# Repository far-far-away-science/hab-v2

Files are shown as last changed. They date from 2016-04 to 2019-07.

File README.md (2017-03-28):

# HAB Version II

Code and hardware designs for a high altitude balloon, the second version of https://github.com/far-far-away-science/hab . This version switches to a more efficient STM32L0 processor, adds support for a backup radio using LoRA, and hopes to include additional sensors.

Different licenses may apply to subsections of this repository. See the appropriate LICENSE files in the desired subdirectories.

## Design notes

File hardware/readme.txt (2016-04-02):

all hardware designs, PCBs, schematics, drawings, specs go into this folder

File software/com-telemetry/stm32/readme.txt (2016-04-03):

this folder contains STM32 SDK and CubeMX project file used to configure hardware.

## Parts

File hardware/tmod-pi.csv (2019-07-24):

Index | Quantity | Part Number | Manufacturer Part Number | Description | Customer Reference | Available | Backorder | Unit Price | Extended Price USD
1 | 1 | SAM8857-ND | SMA-J-P-H-ST-EM1 | CONN SMA JACK STR 50OHM EDGE MNT | LORA | 1 | 0 | 4.33000 | 4.33
2 | 1 | 679-2453-ND | MJTP1250 | SWITCH TACTILE SPST-NO 0.05A 12V | S1 | 1 | 0 | 0.27000 | 0.27
3 | 1 | 311-10KARCT-ND | RC0805JR-0710KL | RES SMD 10K OHM 5% 1/8W 0805 | R6 | 1 | 0 | 0.10000 | 0.10
4 | 2 | D5V0L1B2WS-7DICT-ND | D5V0L1B2WS-7 | TVS DIODE 5V 14V SOD323 | D1 D2 | 2 | 0 | 0.30000 | 0.60
5 | 2 | 1276-2926-1-ND | CL21B105KAFNFNE | CAP CER 1UF 25V X7R 0805 | C3 C5 | 2 | 0 | 0.13000 | 0.26
6 | 10 | 311-100ARCT-ND | RC0805JR-07100RL | RES SMD 100 OHM 5% 1/8W 0805 | R1 R2 R3 R4 | 10 | 0 | 0.03600 | 0.36
7 | 2 | SAM10027-ND | SSW-108-01-F-D | CONN RCPT 16POS 0.1 GOLD PCB | J2L J2R | 2 | 0 | 1.68000 | 3.36
8 | 1 | SAM10033-ND | SSW-113-01-F-D | CONN RCPT 26POS 0.1 GOLD PCB | J1 | 1 | 0 | 2.55000 | 2.55

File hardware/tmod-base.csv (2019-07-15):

Index | Quantity | Part Number | Manufacturer Part Number | Description | Customer Reference | Available | Backorder | Unit Price | Extended Price USD
1 | 12 | 311-1141-1-ND | CC0805KRX7R8BB104 | CAP CER 0.1UF 25V X7R 0805 | C1 C5 C6 C10 C12 C13 C14 C15 C17 C22 C25 C30 | 12 | 0 | 0.11300 | 1.36
2 | 2 | 399-8062-1-ND | C0805C330K5GACTU | CAP CER 33PF 50V C0G/NP0 0805 | C2 C4 | 2 | 0 | 0.12000 | 0.24
3 | 10 | 1276-2926-1-ND | CL21B105KAFNFNE | CAP CER 1UF 25V X7R 0805 | C3 C8 C16 C20 C21 C24 C28 | 10 | 0 | 0.08000 | 0.80
4 | 1 | 1276-1765-1-ND | CL21B331KBANNNC | CAP CER 330PF 50V X7R 0805 | C18 | 1 | 0 | 0.10000 | 0.10
5 | 1 | 1276-1260-1-ND | CL21B332KBANNNC | CAP CER 3300PF 50V X7R 0805 | C26 | 1 | 0 | 0.10000 | 0.10
6 | 1 | 1276-2424-1-ND | CL21B102KBANFNC | CAP CER 1000PF 50V X7R 0805 | C31 | 1 | 0 | 0.10000 | 0.10
7 | 1 | 311-3603-1-ND | CC0805KRX7R9BB101 | CAP CER 100PF 50V X7R 0805 | C19 | 1 | 0 | 0.13000 | 0.13
8 | 1 | P15450CT-ND | EEH-ZA1V151P | CAP ALUM POLY HYB 150UF 35V SMD | C23 | 1 | 0 | 2.57000 | 2.57
9 | 1 | 732-1620-1-ND | 742792040 | FERRITE BEAD 600 OHM 0805 1LN | L1 | 1 | 0 | 0.22000 | 0.22
10 | 1 | 283-4729-1-ND | MPIA4020V2-2R2-R | FIXED IND 2.2UH 3.8A 48 MOHM SMD | L2 | 1 | 0 | 1.80000 | 1.80
11 | 3 | 1276-2397-1-ND | CL21A106KACLRNC | CAP CER 10UF 25V X5R 0805 | C27 C29 C11 | 3 | 0 | 0.57000 | 1.71
12 | 1 | 1655-1529-1-ND | SD32315TR | TVS DIODE 15V 24V SOD323 | D3 | 1 | 0 | 0.52000 | 0.52
13 | 1 | 511-1578-1-ND | SML-D12M8WT86 | LED GREEN DIFFUSED 0603 SMD | D2 | 1 | 0 | 0.34000 | 0.34
14 | 2 | 399-17612-1-ND | C0805C100K5RAC7800 | CAP CER SMD 0805 10PF 10% X7R 50 | C7 C9 | 2 | 0 | 0.30000 | 0.60
15 | 2 | 296-35483-1-ND | TPS70933DBVR | IC REG LINEAR 3.3V 150MA SOT23-5 | IC1 IC10 | 2 | 0 | 1.17000 | 2.34
16 | 1 | 296-23770-1-ND | INA219AIDCNR | IC CURRENT MONITOR 1% SOT23-8 | IC2 | 1 | 0 | 2.14000 | 2.14
17 | 1 | 497-14903-ND | STM32L052C8T6 | IC MCU 32BIT 64KB FLASH 48LQFP | IC3 | 1 | 0 | 4.04000 | 4.04
18 | 1 | LMP7702MM/NOPBCT-ND | LMP7702MM/NOPB | IC OPAMP GP 2.5MHZ RRO 8VSSOP | IC5 | 1 | 0 | 3.55000 | 3.55
19 | 1 | 296-39448-1-ND | TPS62143RGTR | IC REG BUCK 5V 2A SYNC 16QFN | IC6 | 1 | 0 | 2.08000 | 2.08
20 | 1 | 296-46278-1-ND | TPS22918DBVR | IC SINGLE CHANNEL LOAD SWITCH | IC8 | 1 | 0 | 0.55000 | 0.55
21 | 1 | 828-1063-1-ND | BME280 | SENSOR PRESSURE HUMIDITY TEMP | IC9 | 1 | 0 | 8.10000 | 8.10
22 | 1 | 887-1448-1-ND | 7A-8.000MAAJ-T | CRYSTAL 8.0000MHZ 18PF SMD | Y1 | 1 | 0 | 0.72000 | 0.72
23 | 1 | 535-10241-1-ND | ABS25-32.768KHZ-6-1-T | CRYSTAL 32.7680KHZ 6PF SMD | Y2 | 1 | 0 | 0.68000 | 0.68
24 | 1 | 1516-1131-1-ND | QBLP679E-RGB | LED RGB DIFFUSED 6PLCC SMD | LED1 | 1 | 0 | 0.92000 | 0.92
25 | 1 | A121350-ND | 1546215-2 | TERM BLK 2P SIDE ENT 2.54MM PCB | J4 | 1 | 0 | 1.48000 | 1.48
26 | 2 | SAM10451-ND | ESQ-108-14-G-D | CONN SOCKET 16POS 0.1 GOLD PCB | J7 | 2 | 0 | 3.87000 | 7.74
27 | 1 | 455-1720-ND | S3B-PH-K-S(LF)(SN) | CONN HEADER R/A 3POS 2MM | J2 | 1 | 0 | 0.18000 | 0.18
28 | 1 | 455-1721-ND | S4B-PH-K-S(LF)(SN) | CONN HEADER R/A 4POS 2MM | J3 | 1 | 0 | 0.22000 | 0.22
29 | 2 | 679-2453-ND | MJTP1250 | SWITCH TACTILE SPST-NO 0.05A 12V | S1 S2 | 2 | 0 | 0.27000 | 0.54
30 | 1 | 3M5607CT-ND | 2908-05WB-MG | CONN MICRO SD CARD PUSH-PUSH R/A | J6 | 1 | 0 | 3.83000 | 3.83
31 | 2 | 311-4.70KCRCT-ND | RC0805FR-074K7L | RES SMD 4.7K OHM 1% 1/8W 0805 | R6 R16 | 2 | 0 | 0.10000 | 0.20
32 | 10 | 311-10KARCT-ND | RC0805JR-0710KL | RES SMD 10K OHM 5% 1/8W 0805 | R1 R3 R4 R5 R7 R20 R24 R25 | 10 | 0 | 0.03700 | 0.37
33 | 2 | 311-470CRCT-ND | RC0805FR-07470RL | RES SMD 470 OHM 1% 1/8W 0805 | R8 R9 | 2 | 0 | 0.10000 | 0.20
34 | 1 | 311-560CRCT-ND | RC0805FR-07560RL | RES SMD 560 OHM 1% 1/8W 0805 | R10 | 1 | 0 | 0.10000 | 0.10
35 | 3 | 311-3.30KCRCT-ND | RC0805FR-073K3L | RES SMD 3.3K OHM 1% 1/8W 0805 | R11 R17 R19 | 3 | 0 | 0.10000 | 0.30
36 | 1 | 311-330KCRCT-ND | RC0805FR-07330KL | RES SMD 330K OHM 1% 1/8W 0805 | R12 | 1 | 0 | 0.10000 | 0.10
37 | 1 | 311-820KCRCT-ND | RC0805FR-07820KL | RES SMD 820K OHM 1% 1/8W 0805 | R13 | 1 | 0 | 0.10000 | 0.10
38 | 1 | 311-220KCRCT-ND | RC0805FR-07220KL | RES SMD 220K OHM 1% 1/8W 0805 | R14 | 1 | 0 | 0.10000 | 0.10
39 | 1 | 311-430KCRCT-ND | RC0805FR-07430KL | RES SMD 430K OHM 1% 1/8W 0805 | R15 | 1 | 0 | 0.10000 | 0.10
40 | 1 | 311-680KCRCT-ND | RC0805FR-07680KL | RES SMD 680K OHM 1% 1/8W 0805 | R18 | 1 | 0 | 0.10000 | 0.10
41 | 1 | 311-100KCRCT-ND | RC0805FR-07100KL | RES SMD 100K OHM 1% 1/8W 0805 | R21 | 1 | 0 | 0.10000 | 0.10
42 | 12 | D5V0L1B2WS-7DICT-ND | D5V0L1B2WS-7 | TVS DIODE 5V 14V SOD323 | D1 D4-D14 | 12 | 0 | 0.27400 | 3.29
43 | 1 | SAM8857-ND | SMA-J-P-H-ST-EM1 | CONN SMA JACK STR 50OHM EDGE MNT | RF | 1 | 0 | 4.33000 | 4.33
44 | 1 | 311-0.01NACT-ND | RL1210FR-070R01L | RES 0.01 OHM 1% 1/2W 1210 | R22 | 1 | 0 | 0.73000 | 0.73000
45 | 1 | ADXL345BCCZ-RLCT-ND | ADXL345BCCZ-RL | ACCEL 2-16G I2C/SPI 14LGA | U2 | 1 | 0 | 8.14000 | 8.14000

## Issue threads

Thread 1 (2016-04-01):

List APRS messages formats we should be using

usaguerrilla, 2016-04-01:
- potentially with 2 GPS (which ID do we change -11?)
- we need to send this (no need to send all in one message apart from time/GPS coordinate/altitude/number of satellites:
  - time
  - GPS coordinates
  - Altitude
  - Heading
  - Speed
  - Battery voltage
  - Number of satellites
  - Message #
  - CPU temperature (need to research this)
  - Batteries temperature
  - Max acceleration experienced X,Y,Z

Might think about more stuff.

N6UDP, 2016-04-26:
Ok, so the best option is to do a separate telemetry packet after the position one.. example:
2016-04-25 20:39:31 UTC: VK5RAC-1>APNU19,EYRE2-2,qAR,VK5ZEA-1:!3423.56SS13557.24E#PHG5630/ Eyre Pen. Ui-Digi PF75XO @330m
2016-04-25 21:02:05 UTC: VK5RAC-1>TLM,EYRE2-2,qAR,VK5ZEA-1:T#091,048,138,057,021,001,00000000,SA3VFD
As for a Balloon you want it to be something like 4747.50N/12215.10WOTesting
the O being balloon.
As for the format of the telemetry http://www.eoss.org/hardware/w5vsi_gps/telemetry_gps has a good breakdown.  http://www.aprs.net/vm/DOS/TELEMTRY.HTM is the official thing.

usaguerrilla, 2016-07-02:
done

Closed 2016-07-02.

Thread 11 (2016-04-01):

Add temperature sensors and collect information from them

usaguerrilla, 2016-04-01:
- MCU temperature sensors
- Outside temperature
- Battery temperature

usaguerrilla, 2016-04-01:
save to SD and transmit over telemetry channel

usaguerrilla, 2016-04-01:
STM32L0 has sensor and calibration data for it.
http://www.st.com/web/en/resource/technical/document/datasheet/DM00141036.pdf

usaguerrilla, 2016-04-02:
We can also add external temperature sensors on different sides of the package to check how much sun is affecting temperature.

usaguerrilla, 2016-04-04:
ADC which works on SPI
http://www.ti.com/product/ads1247

usaguerrilla, 2016-04-06:
thermal adhesive for contact senosrs

http://www.amazon.com/s/ref=nb_sb_noss_2?url=search-alias%3Daps&field-keywords=Thermal+adhesive

usaguerrilla, 2016-07-08:
will create separate tasks by sensor type.

Closed 2016-07-08.

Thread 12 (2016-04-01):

Add accelerometer sensor (3D) and collect information for it

usaguerrilla, 2016-04-01:
save to SD
send max acceleration to date over telemetry radio channel

usaguerrilla, 2016-07-07:
assigned DMA to I2C.

https://github.com/far-far-away-science/hab-v2/wiki/dma_usage

usaguerrilla, 2016-07-08:
See sensors list:
https://github.com/far-far-away-science/hab-v2/wiki/sensors_list

stcarlso, 2017-09-15:
Implemented in Phoenix, accelerometer data is read and logged over serial port

Closed 2017-09-15.

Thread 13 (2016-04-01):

Add medium altitude pressure sensors and collect infromation from them

usaguerrilla, 2016-04-01:
Do we want to collect pressure close to the ground?
Do we want pressure from up high?
Pick sensors.
Need to save to SD.
Should we send it over the radio once in a while?

usaguerrilla, 2016-04-04:
http://www.ebay.com/itm/Sensore-pressione-MD-PS002-vacuum-sensor-absolute-pressure-senso-for-Arduino-/191674522193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

http://www.ebay.com/itm/Freescale-MPXV6115VC6U-vacuum-sensor-115-to-0-kPa-16-7-to-0-psi-USA-seller-/231887983618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

usaguerrilla, 2016-04-07:
for this task use one of these sensors (lower altitude ones):

http://www.digikey.com/product-search/en/sensors-transducers/pressure-sensors-transducers/1966259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

usaguerrilla, 2016-07-08:
sensor make and model are in the sensors list in wiki
this is an SPI sensor.

usaguerrilla, 2016-07-08:
Sensors list:
https://github.com/far-far-away-science/hab-v2/wiki/sensors_list

stcarlso, 2017-09-15:
BME280 sensor is implemented in Phoenix

Closed 2017-09-15.

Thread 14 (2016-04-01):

Add camera which will record balloon pop event

usaguerrilla, 2016-04-01:
Need to record pop event. No need to record full flight. Don't need very high resolution. Should be software controlled to cut power consumption.

Do we need extra MCU for it?
Save to separate SD card?

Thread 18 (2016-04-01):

Gyro-stabilized camera 1x

usaguerrilla, 2016-04-01:
Check if it's possible and how much will it weigh.

usaguerrilla, 2016-07-08:
not going to make it for V2

Closed 2016-07-08.

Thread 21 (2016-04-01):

Add LORA or other radio options to supplement APRS for package recovery

usaguerrilla, 2016-04-01:
Check power requirements.
Turn them on, once package lands.

usaguerrilla, 2016-06-07:
LORA should:

- after we turn on electronics on the ground LORA should power up and start transmitting for 5 minutes (every 15 seconds or so, duration and delay can be discussed). We want to make sure it works.
- after this it should power down
- when altitude is < 3 km LORA should again power up (as range is something like 10km) we might receive messages from it in case something is wrong with APRS and vice versa and transmit every 30 seconds or so
- when on the ground for 1st 3 hours it should keep transmitting every 15-30 seconds or so (check how much power will it consume)
- after 3 hours it should transmit every 15-30 minutes

to discuss: do we need to handle case where it landed one a moving object (river, truck) and do we need to transmit more often in this case?

stcarlso, 2017-09-15:
Implemented in Phoenix, LoRA is active at all times and transmits with APRS.

Closed 2017-09-15.

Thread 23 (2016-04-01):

Ultrasonic temperature / pressure sensor

usaguerrilla, 2016-04-01:

usaguerrilla, 2016-04-07:
Please note that priority of interrupts for this sensor will be after:
- APRS signal generation
- GPS data reception
Not sure how critical it will be to have 3rd priority.

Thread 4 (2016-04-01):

Add support to write to persistent storage SD?

usaguerrilla, 2016-04-01:
We want as much space as possible. As we want to collect data often and a lot of it. This will include all sensors data.

- choose parts (SD, FLASH, EEPROM?), > 10M? Needs discussion.
- PCB design

usaguerrilla, 2016-04-01:
For some date we need around 2-3 hours storage. For small subset we might need 12-24 hours storage.

usaguerrilla, 2016-04-01:
Also some data will have higher sampling rate than other.
- GPS -> once a second or so
- Accelerometers -> 10-100 times a second
- Temperature -> once in 1-15 seconds
We can use binary storage if we are tight on space.

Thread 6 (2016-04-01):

Add light sensors for GoPros or other ways of detecting if they are recording.

usaguerrilla, 2016-04-01:
When GoPro records light is blinking. We can add sensor of red light next to it to detect if recording is running and transmit it with telemetry.

Alternatively investigate if it's possible to get telemetry using USB or other means with GoPro4.

usaguerrilla, 2016-07-08:
See sensors list:
https://github.com/far-far-away-science/hab-v2/issues/6

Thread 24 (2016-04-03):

Migrate Copernicus GPS code to STM32

usaguerrilla, 2016-04-03:

usaguerrilla, 2016-04-06:
requirements:
* code should support recovery from temporary loss of power or reset and loading last known position to transmit over APRS (with flag of stale information).
* new position should be transmitted as soon as GPS acquires lock
* this is the 2nd highest priority after APRS signal modulation
* GPS should not be updated more than once a second

recovery data requirements:
* recovery data will be stored in EEPROM in both banks
* each bank will have ring buffer for 50 records (after we reach end we start overwriting old records). 50 was picked to prolong EEPROM lifetime.
* on reboot we will scan all records (from banks which are online, if bank is offline for writing wait for read operation to be completed before restoring the data) and use latest one
* banks will be written in round robin style (bank 1, bank 2, bank 1, etc.)

recovery record spec:
* TODO

open items:
* what will happen if during EEPROM write operation MCU reboots or has fault ISR or power off event
* how to determine buffer writing round robin order

usaguerrilla, 2016-04-06:
Unlock with wait until write is completed:
/* (1) Wait till no operation is on going */
/* (2) Check if the PELOCK is unlocked */
/* (3) Perform unlock sequence */
while ((FLASH->SR & FLASH_SR_BSY) != 0) /* (1) */
{
/* For robust implementation, add here time-out management */
}
if ((FLASH->PECR & FLASH_PECR_PELOCK) != 0) /* (2) */
{
FLASH->PEKEYR = FLASH_PEKEY1; /* (3) */
FLASH->PEKEYR = FLASH_PEKEY2;
}

usaguerrilla, 2016-04-06:
Lock with wait until write is completed:

```
/* (1) Wait till no operation is on going */
/* (2) Locks the NVM by setting PELOCK in PECR */
while ((FLASH->SR & FLASH_SR_BSY) != 0) /* (1) */
{
/* For robust implementation, add here time-out management */
}
FLASH->PECR |= FLASH_PECR_PELOCK; /* (2) */
```

usaguerrilla, 2016-04-06:
Write to data EEPROM code example
```
*(uint8_t *)(DATA_E2_ADDR+i) = DATA_BYTE;
*(uint16_t *)(DATA_E2_ADDR+j) = DATA_16B_WORD;
*(uint32_t *)(DATA_E2_ADDR) = DATA_32B_WORD;
```
DATA_E2_ADDR is an aligned address in the data EEPROM area.
i can be any integer.
j must be an even integer.

usaguerrilla, 2016-04-06:
Erase to data EEPROM code example
/* (1) Set the ERASE and DATA bits in the FLASH_PECR register
to enable page erasing */
/* (2) Write a 32-bit word value at the desired address
to start the erase sequence */
/* (3) Enter in wait for interrupt. The EOP check is done in the Flash ISR
*/
/* (6) Reset the ERASE and DATA bits in the FLASH_PECR register
to disable the page erase */
FLASH->PECR |= FLASH_PECR_ERASE | FLASH_PECR_DATA; /* (1) */
*(__IO uint32_t *)addr = (uint32_t)0; /* (2) */
__WFI(); /* (3) */
FLASH->PECR &= ~(FLASH_PECR_ERASE | FLASH_PECR_DATA); /* (4) */

Scorillo47, 2016-04-06:
My suggestion would be something along these lines (pseudo-code only - I didn’t add CRC, sequence#, Flash synchronization, etc). Sorry for the Outlook-enforced capitalization:

Bool Write(data)
{
                For(int = 0; I < maxAddressesToBeTried; i++)
                {
                                addr = PickUpNextLocation(); // alternate banks round-robin, etc.
                                For(int = 0; I < maxRetries; i++)
                                {
                                                If (Write(data, addr) == success)
                                                {
                                                                // wait a bit …

                                                                // Read after write to ensure the correct data is there
                                                                Data1 = Read(addr);
                                                                If (Data == Data1)
                                                                {
                                                                                Return true;
                                                                }
                                                }

                                                // Writing failed (bad block?)

                                                // wait a bit more …                                

                                                // retry writing on the same location maxRetries
                                }
                                // give up on this address. Try writing on the next location (up to maxAddressesToBeTried tries)
                }

                Return false;
}

usaguerrilla, 2016-04-07:
algorithm in a nutshell:

```
isDataValid(address)
{
    return true if crc(from sequence id and payload at this address) == crc(crc at this address) else false
}

recoverDataFromBank(bankAddress, currentMaxSequenceId)
{
    if (!waitUntilBankIsAvailable(TIMEOUT))
    {
        return (none, none)
    }
    data = none
    maxSequenceId = currentMaxSequenceId
    foreach (address in bankAddress)
    {
        if (isDataValid(address) && getId(address) > maxSequenceId)
        {
            data = getData(address)
            maxSequenceId = getId(address)
        }
    }
    return (data, maxSequenceId)
}

recoverGpsData(data)
{
    sequence_id maxGoodId;
    (data, sequence_id) = recoverDataFromBank(Bank1Address, none)
    (data, sequence_id) = recoverDataFromBank(Bank2Address, sequence_id)
    return data != none
}
```

usaguerrilla, 2016-04-07:
update recovery algorithm in a nutshell:

```
updateRecoveryData(data)
{
}
```

usaguerrilla, 2016-04-07:
This algorithm protects against the following problems:

* MCU resets (or experiences short power interruption) and we cannot communicate with GPS after power on
* GPS unit looses last known good position or overwrites it with the empty position message

* This algorithm / hardware design is:
* (2*N-2)x fail operational / fail safe for EEPROM individual memory cells failures (couldn't read or couldn't write at specific addresses).
* fail safe for EEPROM data banks (as we have 2 and failure of one bank will still leave system running).
* fail safe for GPS loosing last known good position

N - size of a ring buffer in one EEPROM memory bank

usaguerrilla, 2016-05-05:
code migrated. gps backup will be done by #37

Closed 2016-05-05.

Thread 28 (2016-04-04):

Infrared camera inside the case to check cooling video

usaguerrilla, 2016-04-04:

usaguerrilla, 2016-04-04:
https://www.sparkfun.com/products/11610

usaguerrilla, 2016-04-04:
Above camera might not be what we need for this. Need to test.

usaguerrilla, 2016-04-06:
https://hackaday.io/project/3000-flir-lepton-thermal-camera-breakout

http://www.digikey.com/product-detail/en/flir/500-0659-01/500-0659-01-ND/5215153

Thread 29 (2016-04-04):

Add gamma/beta/xray detector

usaguerrilla, 2016-04-04:
Make sure to estimate weight / power consumption / size before starting work.

usaguerrilla, 2016-04-10:
By Adi's estimate weight is 290gr. Way to heavy if we want to make a video!

usaguerrilla, 2016-07-08:
didn't make it for V2 as board layout is fixed now.

Closed 2016-07-08.

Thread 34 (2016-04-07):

Add high altitude pressure sensors and collect infromation from them

usaguerrilla, 2016-04-07:

usaguerrilla, 2016-04-10:
hard to get sensors to do this job. not sure if they are light. we have sensors which will work up to 25-28 km or so.

usaguerrilla, 2016-07-08:
not a target for V2

Closed 2016-07-08.

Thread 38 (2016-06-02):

Migrate UART to use DMA and UART IDLE interrupt

usaguerrilla, 2016-06-02:
AFSK modulator on release build loads CPU for 86%. I don't want UART to interrupt AFSK message generation nor I want GPS coordinates to be lost from UART.

Proposed solution:
- migrate UART to receive using DMA feature (allocate memory for more than 1 message)
- end of message can be detected by UART IDLE interrupt or DMA full and memory can be copied to ring buffer
- in main() thread parse and process NMEA messages

this will remove code from interrupts and CPU will be free to handle AFSK modulation.

Scorillo47, 2016-06-02:
86% CPU for a modulator? We should just use a faster CPU

Sent from my Windows Phone
________________________________
De la: Pavel Krupets<mailto:notifications@github.com>
Trimis: ‎02.‎06.‎2016 9:47
Către: far-far-away-science/hab-v2<mailto:hab-v2@noreply.github.com>
Subiect: [far-far-away-science/hab-v2] Migrate UART to use DMA and UART IDLE interrupt (#38)

AFSK modulator on release build loads CPU for 86%. I don't want UART to interrupt AFSK message generation nor I want GPS coordinates to be lost from UART.

Proposed solution:
- migrate UART to receive using DMA feature (allocate memory for more than 1 message)
- end of message can be detected by UART IDLE interrupt and memory can be copied to ring buffer
- in main() thread parse and process NMEA messages

this will remove code from interrupts and CPU will be free to handle AFSK modulation.

---
You are receiving this because you are subscribed to this thread.
Reply to this email directly or view it on GitHub:
https://github.com/far-far-away-science/hab-v2/issues/38

usaguerrilla, 2016-06-02:
I want this to work on a slowest CPU possible so code can be ported to circumnavigating balloon.

I did this test:
do (a * b + c / d) and write to RAM on 16MHz at 96kHz and it loaded CPU 30%. Adding read from program memory increased it to 50% so I don't think I can optimize much. Division might be slowest operation.

usaguerrilla, 2016-06-02:
By 86% I mean CPU was running at full speed and consumed 86% of available time to fill DMA buffer.

usaguerrilla, 2016-06-02:
Also DMA for UART will save us from getting to many interrupts which is good as well. I wasn't sure how to detect when UART finished transmitting but DMA buffer isn't full.

After reading specs it seems UART IDLE interrupt will be fired in this case and I can copy memory from DMA buffer to ring buffer for later processing.

So instead of handling interrupt for each symbol I will have 2 interrupts: UART IDLE, DMA BUFFER FULL

Scorillo47, 2016-06-02:
I see. How long is the duty cycle for this computation? Maybe it's not a problem if it's very small.
BTW, I don't think this particular CPU implements hardware division - this could be an issue making the computation much longer.
Is the "d" constant, BTW? We can use tricks to divide faster by certain type of constants (bit shifts, addition, etc)
Also, the a*b + c type of expressions can be optimized to be much faster by using DSP instructions from ARM Cortex-M4 (I presume we are talking about integer operations, not floating point)

Adi

Date: Thu, 2 Jun 2016 10:10:53 -0700
From: notifications@github.com
To: hab-v2@noreply.github.com
CC: adi_oltean@hotmail.com; comment@noreply.github.com
Subject: Re: [far-far-away-science/hab-v2] Migrate UART to use DMA and UART IDLE interrupt (#38)

I want this to work on a slowest CPU possible so code can be ported to circumnavigating balloon.

I did this test:

do (a * b + c / d) and write to RAM on 16MHz at 96kHz and it loaded CPU 30%. Adding read from program memory increased it to 50% so I don't think I can optimize much. Division might be slowest operation.

—
You are receiving this because you commented.
Reply to this email directly, view it on GitHub, or mute the thread.

usaguerrilla, 2016-06-02:
We aren't using M4. AFSK modulation works so I don't see a problem. Changing to use DMA for UART also isn't a big deal.

usaguerrilla, 2016-06-02:
optimizations for shifts and * will be done at the end when we know signal generation frequency, CPU frequency, etc. For now it's enough that it works on target CPU.

stcarlso, 2016-06-07:
The division is the killer here. Can you make it a shift? Shifts are usually free.

usaguerrilla, 2016-06-07:
Yeh. After I make sure precision for each operation is optimized I will replace divisions by shifts / muls.

n / 1'000'000 for instance will be replaced (if it stays) with ((n >> 6) * 67) >> 20)

This improves duty cycle from 86% to 40%.

I am still able to receive message from short distance need to test longer distances though.

usaguerrilla, 2016-06-07:
Main thing is that even without this speedup code works so we can make PCB for final testing, as testing long distance with breadboard is not very clever.

usaguerrilla, 2016-07-06:
we don't have enough DMA channels for this. Will have to live with interrupt.

Closed 2016-07-06.

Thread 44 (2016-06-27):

Is it okay that DAC input goes to negative OPAMP port?

usaguerrilla, 2016-06-27:
Subj.

usaguerrilla, 2016-06-27:
Need to review AFSK filter. You made some changes to it.
I should get breakout boards soon so I will be able to test final version.

stcarlso, 2016-06-27:
This was an oversight. It has been corrected. Thank you for reviewing!

Closed 2016-06-27.

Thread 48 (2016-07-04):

Add tricolor LED for STM32

usaguerrilla, 2016-07-04:
Currently enable HX1 and built in user LED are on the same port A5

usaguerrilla, 2016-07-06:
done (well might need to fiddle with duty cycle to save power but I need to solder RGB LED to check how bright is it)

Closed 2016-07-06.

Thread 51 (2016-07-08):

Read battery voltage and store it in telemetry structure

usaguerrilla, 2016-07-08:

usaguerrilla, 2016-07-08:
Battery voltage is read using MCU ADC. See sensor list for more info.
github.com/far-far-away-science/hab-v2/wiki/sensors_list

Closed 2017-04-09.

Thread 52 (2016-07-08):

Build LORA receivers

usaguerrilla, 2016-07-08:
We need at least 2 of them. We can duct-tape them on NUCLEO boards.

stcarlso, 2017-09-15:
Implemented in Phoenix, LoRA receiver board design created (lora-rx.sch / lora-rx.brd) and firmware to report LoRA packets to UWP app

Closed 2017-09-15.

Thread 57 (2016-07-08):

Collect CPU temperature

usaguerrilla, 2016-07-08:
Place CPU temperature from built-in sensor into telemetry structure.
Check if calibration is needed, calibration table is in MCU's ROM.
See specs for more info.

usaguerrilla, 2016-07-08:
See sensor list for more info: https://github.com/far-far-away-science/hab-v2/wiki/sensors_list

Closed 2017-04-09.

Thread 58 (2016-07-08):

Collect Battery and GPS chip temperature

usaguerrilla, 2016-07-08:
These are simple analogue temperature sensors (see sensors list) read through MCU ADC ports.
No need to read them more than once in 1-5 minutes.
Save to telemetry / SD (once this functionality is finished).

usaguerrilla, 2016-07-08:
See sensor list for more info
https://github.com/far-far-away-science/hab-v2/wiki/sensors_list

stcarlso, 2017-09-15:
External DS18(B)20 sensors are implemented in Phoenix

Closed 2017-09-15.

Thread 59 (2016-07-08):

Read payload / outside humitity and temperature (from HIH9000 Series sensor)

usaguerrilla, 2016-07-08:
see sensor list for more info.
https://github.com/far-far-away-science/hab-v2/wiki/sensors_list

stcarlso, 2017-09-15:
Payload temperature and humidity is read by the BME280 series sensor.

Closed 2017-09-15.

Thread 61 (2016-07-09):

SPI DMA should be initialized every time before sending and receiving data to/from SPI

usaguerrilla, 2016-07-09:
DMA is shared with DAC1 but SPI won't run at the same time as DAC1.

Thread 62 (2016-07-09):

DAC1 DMA should initialize every time before using DAC1

usaguerrilla, 2016-07-09:
DAC1 and SPI1 share the same DMA but they won't run together.

usaguerrilla, 2016-07-11:
done

Closed 2016-07-11.

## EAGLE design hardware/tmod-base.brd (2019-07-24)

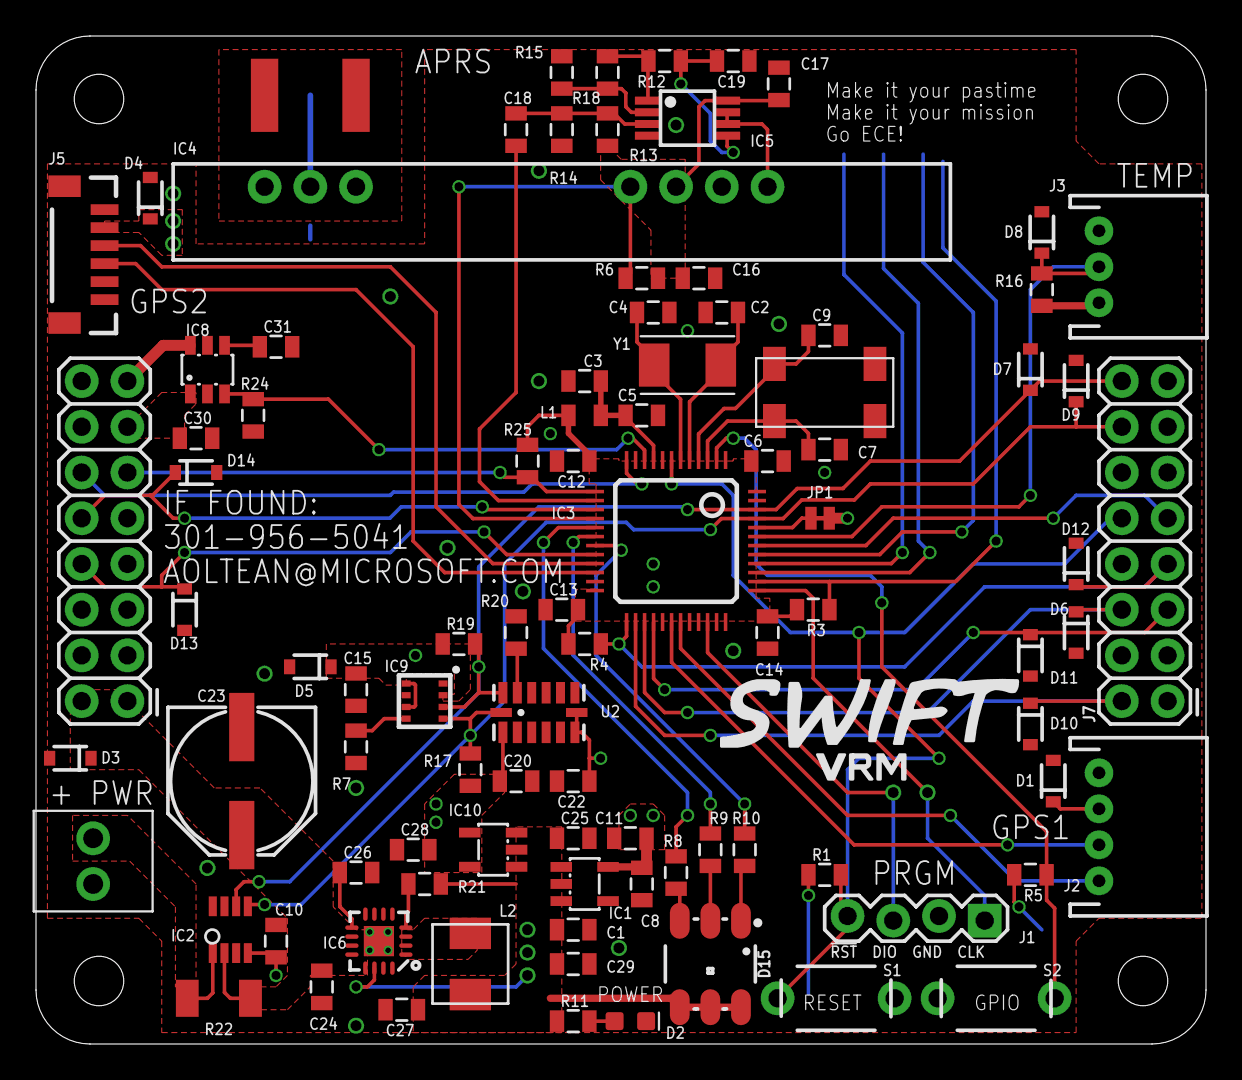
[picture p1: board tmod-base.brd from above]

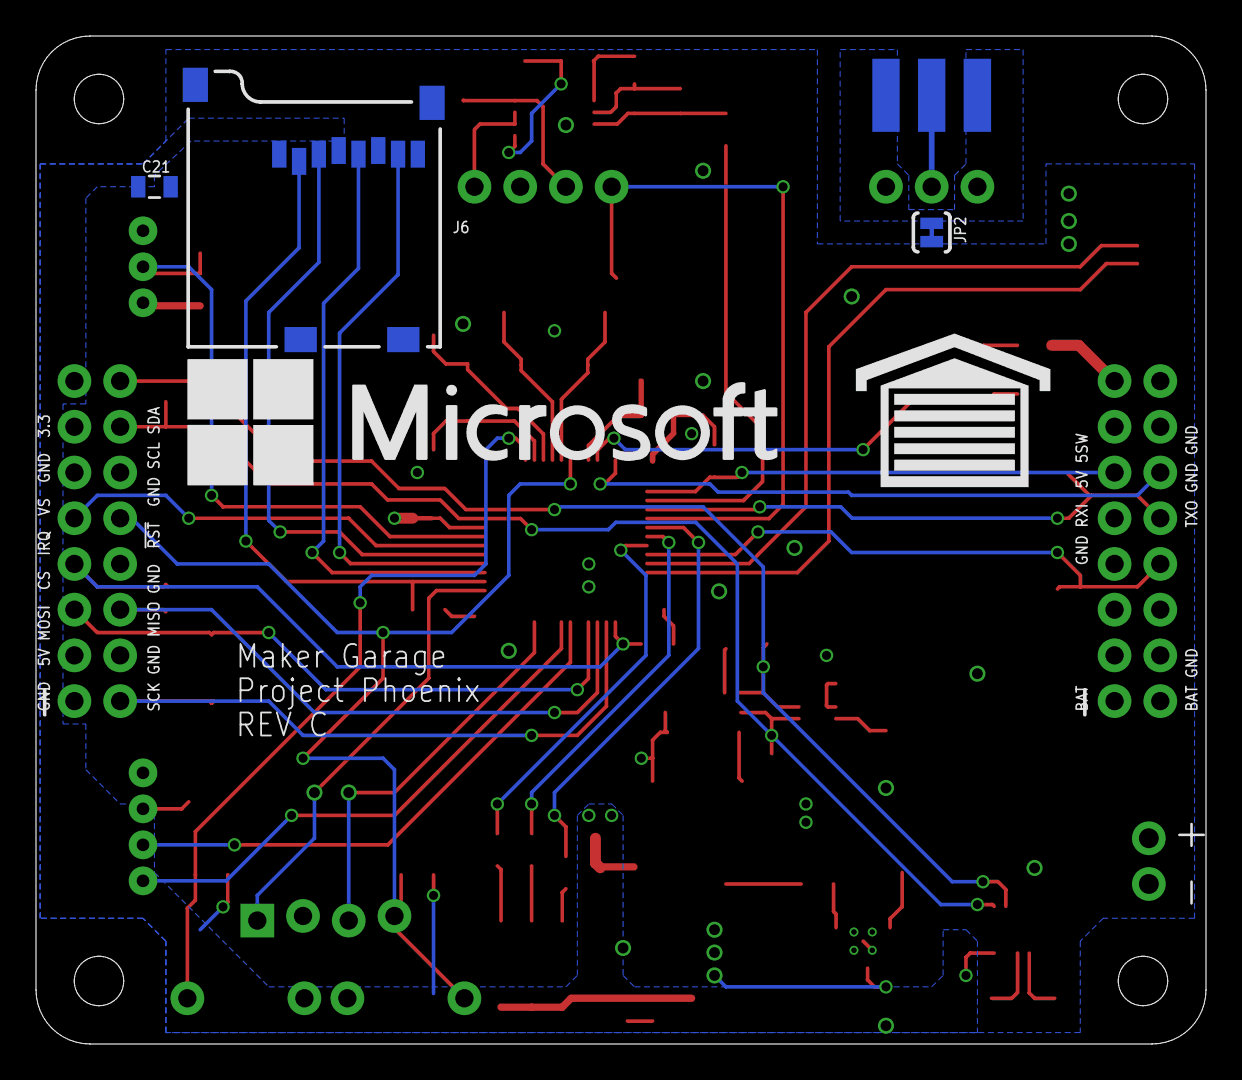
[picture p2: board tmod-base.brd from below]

Board: 4 copper layers, 65.0 x 56.0 mm, 100 parts (6 on the bottom side), 60 nets.

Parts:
C1, C5, C6, C10, C12, C13, C14, C15, C17, C22, C25, C30: 0.1u; 0805
C2, C4: 33p; 0805
C3, C8, C16, C21, C24, C28: 1u; 0805
C7, C9: 10p; 0805
C11, C27, C29: 10u; 0805
C18: 330p; 0805
C19: 100p; 0805
C20: 1.0u; 0805
C23: 150u; PANASONIC_E
C26: 3.3n; 0805
C31: 1n; 0805
D1, D4, D5, D6, D7, D8, D9, D10, D11, D12, D13, D14: 5.6V; SOD-323
D2: POWER; LED-0603
D3: 15V; SOD-323
D15: LED-RGB; LED-TRICOLOR-5050
FRAME1, FRAME2: FRAME-LETTERNO_PACKAGE; DUMMY
IC1, IC10: TPS70933; SOT23-DBV
IC2: INA219SOT; SOT23-8
IC3: STM32L443CCT6; TQFP48
IC4: HX1
IC5: LMP7702; VSSOP8
IC6: TPS62143; QFN16-3X3MM
IC8: TPS22918; SOT23-6L
IC9: BME280; BME280_LGA
J1: DNP; 1X04_LOCK@1
J2: GPS1; JST-4-PTH
J3: TEMP; JST-3-PTH
J4: POWER; 1X02_SCREW
J5: GPS2; 1X06-1MM
J6: MICRO-SD_CARD_SOCKET; MICRO-SD-SOCKET
J7: HAB-EXP
J$1: SMA_EDGE; SMA-EDGE
JP1: SMT-JUMPER_2_NC_TRACE_NO-SILK
JP2: GND; PAD-JUMPER-2-NC_BY_TRACE_YES_SILK
L1: FERRITE; 0805
L2: 2.2u; MPIA4012V2
R1, R3, R4, R5, R7, R20, R24, R25: 10K; 0805
R6, R16: 4.7K; 0805
R8, R9: 470; 0805
R10: 560; 0805
R11, R17, R19: 3.3K; 0805
R12: 330K; 0805
R13: 820K; 0805
R14: 220K; 0805
R15: 430K; 0805
R18: 680K; 0805
R21: 100K; 0805
R22: 0.01; 1210
S1: RST; TACTILE-PTH-THIN
S2: BTN; TACTILE-PTH-THIN
U2: ADXL345; LGA14
U$1: MSFT_LOGO
U$2: GARAGE
U$3: SWIFT
Y1: 8M; CRYSTAL-TXC-7A
Y2: 32768; ABS25

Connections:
3.3V: C6.1, C8.1, C10.1, C11.1, C12.1, C13.1, C14.1, C21.1, D1.C, IC1.5, IC2.4, IC3.1, IC3.24, IC3.36, IC3.48, J2.2, J6.VCC, J7.B15, L1.1, R1.2, R3.2, R4.2, R5.2, R25.2
5V: C1.1, C16.1, C17.1, C25.1, C27.1, C29.1, C30.1, D4.C, D15.4, D15.5, D15.6, IC1.1, IC4.5, IC5.8, IC6.14, IC8.1, IC10.1, J5.2, J7.A13, J7.B3, L2.2, R6.2, R11.1, R13.2, R21.2
5V_PI: IC8.6, J7.A15
!RST!: IC3.7, J1.4, J7.B10, R1.1, S1.2
A+: C18.2, IC5.3, R13.1, R14.2
A-: IC5.2, R15.2, R18.1
ADXL_SDO: R20.2, U2.12
BC: D15.1, R10.2
BME_SDO: IC9.P$5, R7.2
BOOT0: IC3.44, JP1.1
BTN: IC3.2, R5.1, S2.2
CT: C31.1, IC8.4
DAC: C18.1, IC3.14
GC: D15.2, R9.2
GND: C1.2, C2.2, C3.2, C4.2, C5.2, C6.2, C7.2, C8.2, C9.2, C10.2, C11.2, C12.2, C13.2, C14.2, C15.2, C16.2, C17.2, C19.2, C20.2, C21.2, C22.2, C23.-, C24.2, C25.2, C26.2, C27.2, C28.2, C29.2, C30.2, C31.2, D1.A, D2.C, D3.A, D4.A, D5.A, D6.A, D7.A, D8.A, D9.A, D10.A, D11.A, D12.A, D13.A, D14.A, IC1.2, IC2.3, IC2.7, IC2.8, IC3.8, IC3.23, IC3.35, IC3.47, IC4.6, IC5.4, IC6.5, IC6.6, IC6.7, IC6.8, IC6.15, IC6.16, IC6.EXT, IC8.2, IC9.P$1, IC9.P$7, IC10.2, J1.2, J2.1, J3.1, J4.2, J5.1, J5.5, J6.GND, J6.GND1, J6.GND3, J7.A4, J7.A9, J7.A14, J7.A16, J7.B1, J7.B4, J7.B8, J7.B12, J7.B13, JP1.2, JP2.2, R7.1, R14.1, R15.1, R20.1, R24.2, S1.1, S2.1, U2.2, U2.4, U2.5
GPSRX1: IC3.31, J2.4
GPSRX2: IC3.22, J5.4
GPSTX1: IC3.30, J2.3
GPSTX2: IC3.21, J5.3
HXEN: IC3.16, IC4.4, R6.1
K_PI: IC3.10, IC8.3, R24.1
LCS: D12.C, IC3.25, J7.B7, R4.1
LEDB: IC3.19, R10.1
LEDG: IC3.18, R9.1
LEDR: IC3.17, R8.1
LP1: IC5.1, R12.1, R18.2
LP2: C19.1, IC5.5, R12.2
MISO1: IC3.40, J6.DO
MISO2: D6.C, IC3.27, J7.B6
MOSI1: IC3.41, J6.DI
MOSI2: D11.C, IC3.28, J7.B5
OSC32_IN: C7.1, IC3.3, Y2.1
OSC32_OUT: C9.1, IC3.4, Y2.4
OSC_IN: C2.1, IC3.5, Y1.P$1
OSC_OUT: C4.1, IC3.6, Y1.P$2
PG5: IC6.4, R21.1
PLED: D2.A, R11.2
RC: D15.3, R8.2
RF_HX1: IC4.2, J$1.SIG
RGND: IC4.1, IC4.3, J$1.GND@0, J$1.GND@1, J$1.GND@2, J$1.GND@3, JP2.1
RSV5: D13.C, IC3.20, J7.A8
RSV6: D14.C, IC3.15, J7.A10
RSV7: IC3.42, J7.B9
R_RX: IC3.13, J7.A11, R25.1
R_TX: IC3.12, J7.A12
SCK1: IC3.39, J6.SCLK
SCK2: D10.C, IC3.26, J7.B2
SCL: D9.C, IC2.5, IC3.45, IC9.P$4, J7.B14, R17.1, U2.14
SDA: D7.C, IC2.6, IC3.46, IC9.P$3, J7.B16, R19.1, U2.13
SDCS: IC3.38, J6.CS, R3.1
SS5: C26.1, IC6.9
SW5: IC6.1, IC6.2, IC6.3, L2.1
SWCLK: IC3.37, J1.1
SWDIO: IC3.34, J1.3
TEMP: D8.C, IC3.43, J3.2, R16.1
TXD: IC4.7, IC5.6, IC5.7
VBAT: C23.+, C24.1, D3.C, IC2.2, IC6.10, IC6.11, IC6.12, IC6.13, J7.A1, J7.A2, R22.1
VDDA: C3.1, C5.1, IC3.9, L1.2
VIN: IC2.1, J4.1, R22.2
VS: C15.1, C20.1, C22.1, C28.1, D5.C, IC9.P$2, IC9.P$6, IC9.P$8, IC10.5, J3.3, J7.B11, R16.2, R17.2, R19.2, U2.1, U2.6, U2.7

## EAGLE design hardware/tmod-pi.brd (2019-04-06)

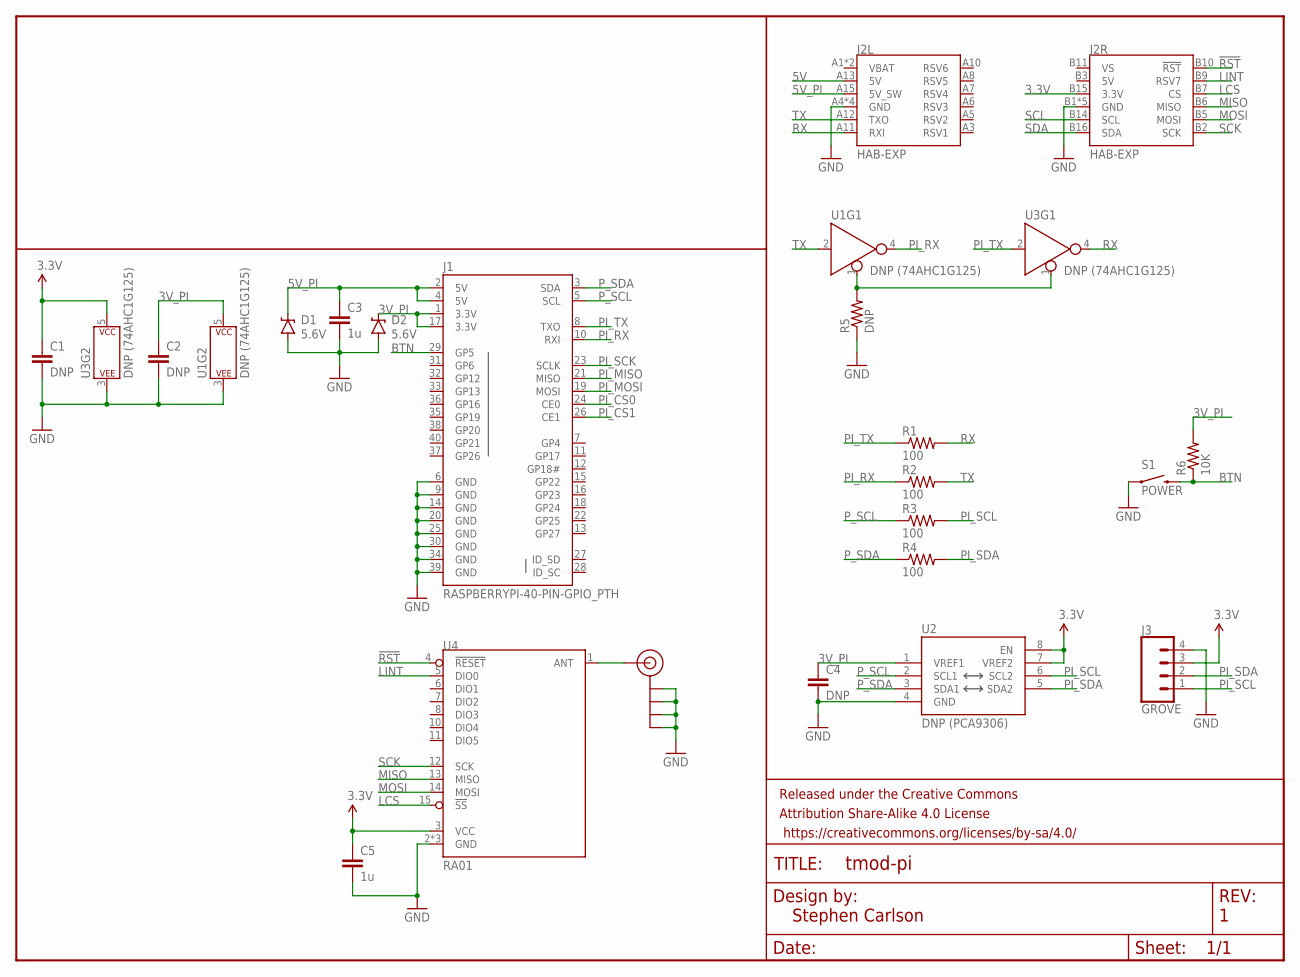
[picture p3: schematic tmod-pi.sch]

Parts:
C1, C2, C4: DNP; 0805
C3, C5: 1u; 0805
D1, D2: 5.6V; SOD-323
FRAME1: FRAME-LETTERNO_PACKAGE; DUMMY
J1: RASPBERRYPI-40-PIN-GPIO_PTH; 2X20_SHROUDED
J2: HAB-EXP
J3: GROVE; JST-4-PTH
J4: SMA_EDGE; SMA-EDGE
R1, R2, R3, R4: 100; 0805
R5: DNP; 0805
R6: 10K; 0805
S1: POWER; TACTILE-PTH-THIN
U1, U3: DNP (74AHC1G125); SOT23-5
U2: DNP (PCA9306); PCA9306DC
U4: RA01

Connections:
3.3V: C1.1, C5.1, J2.B15 (3.3V), J3.3, U2.7 (VREF2), U2.8 (EN), U3.5 (P$V+), U4.3 (VCC)
3V_PI: C2.1, C4.1, D2.C, J1.1 (3.3V), J1.17 (3.3V), R6.2, U1.5 (P$V+), U2.1 (VREF1)
5V: J2.A13 (5V), J2.B3 (5V)
5V_PI: C3.1, D1.C, J1.2 (5V), J1.4 (5V), J2.A15 (5V_SW)
!RST!: J2.B10 (!RST!), U4.4 (!RESET!)
ANT: J4.SIG (SIGNAL), U4.1 (ANT)
BTN: J1.29 (GP5), R6.1, S1.2
GND: C1.2, C2.2, C3.2, C4.2, C5.2, D1.A, D2.A, J1.6 (GND), J1.9 (GND), J1.14 (GND), J1.20 (GND), J1.25 (GND), J1.30 (GND), J1.34 (GND), J1.39 (GND), J2.A4 (GND), J2.A9 (GND), J2.A14 (GND), J2.A16 (GND), J2.B1 (GND), J2.B4 (GND), J2.B8 (GND), J2.B12 (GND), J2.B13 (GND), J3.4, J4.GND@0 (GND), J4.GND@1 (GND), J4.GND@2 (GND), J4.GND@3 (GND), R5.1, S1.1, U1.3 (P$V-), U2.4 (GND), U3.3 (P$V-), U4.2 (GND), U4.9 (GND), U4.16 (GND)
LCS: J2.B7 (CS), U4.15 (!SS!)
LINT: J2.B9 (RSV7), U4.5 (DIO0)
MISO: J2.B6 (MISO), U4.13 (MISO)
MOSI: J2.B5 (MOSI), U4.14 (MOSI)
PI_CS0: J1.24 (CE0)
PI_CS1: J1.26 (CE1)
PI_MISO: J1.21 (MISO)
PI_MOSI: J1.19 (MOSI)
PI_RX: J1.10 (RXI), R2.1, U1.4 (Y)
PI_SCK: J1.23 (SCLK)
PI_SCL: J3.1, R3.2, U2.6 (SCL2)
PI_SDA: J3.2, R4.2, U2.5 (SDA2)
PI_TX: J1.8 (TXO), R1.1, U3.2 (A)
P_SCL: J1.5 (SCL), R3.1, U2.2 (SCL1)
P_SDA: J1.3 (SDA), R4.1, U2.3 (SDA1)
RX: J2.A11 (RXI), R1.2, U3.4 (Y)
SCK: J2.B2 (SCK), U4.12 (SCK)
SCL: J2.B14 (SCL)
SDA: J2.B16 (SDA)
TX: J2.A12 (TXO), R2.2, U1.2 (A)
UART_EN: R5.2, U1.1 (!EN), U3.1 (!EN)
VBAT: J2.A1 (VBAT), J2.A2 (VBAT)
VS: J2.B11 (VS)

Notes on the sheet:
Stephen Carlson

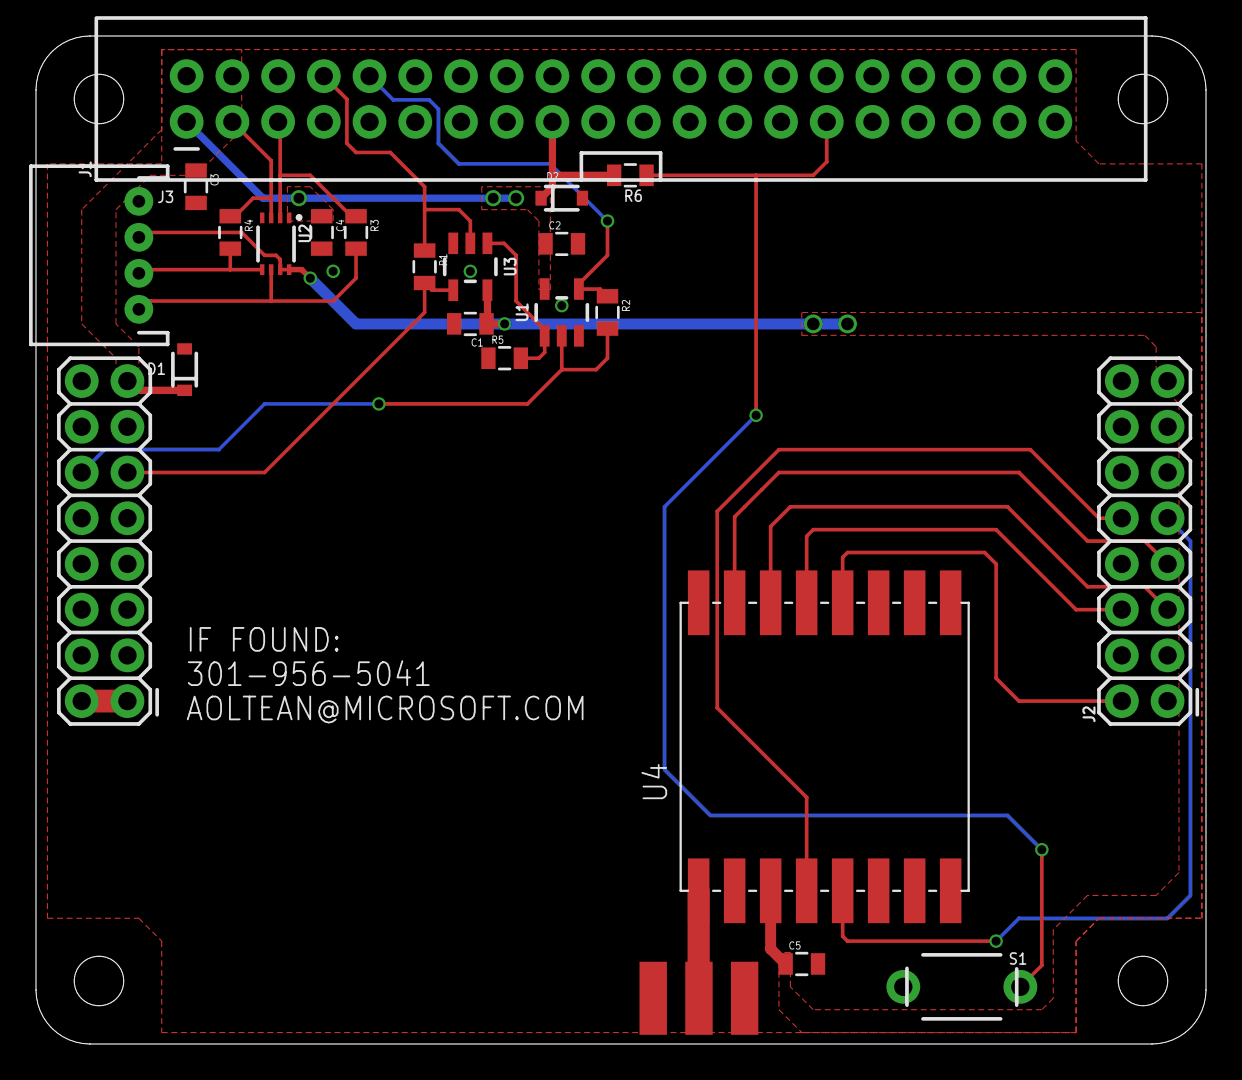
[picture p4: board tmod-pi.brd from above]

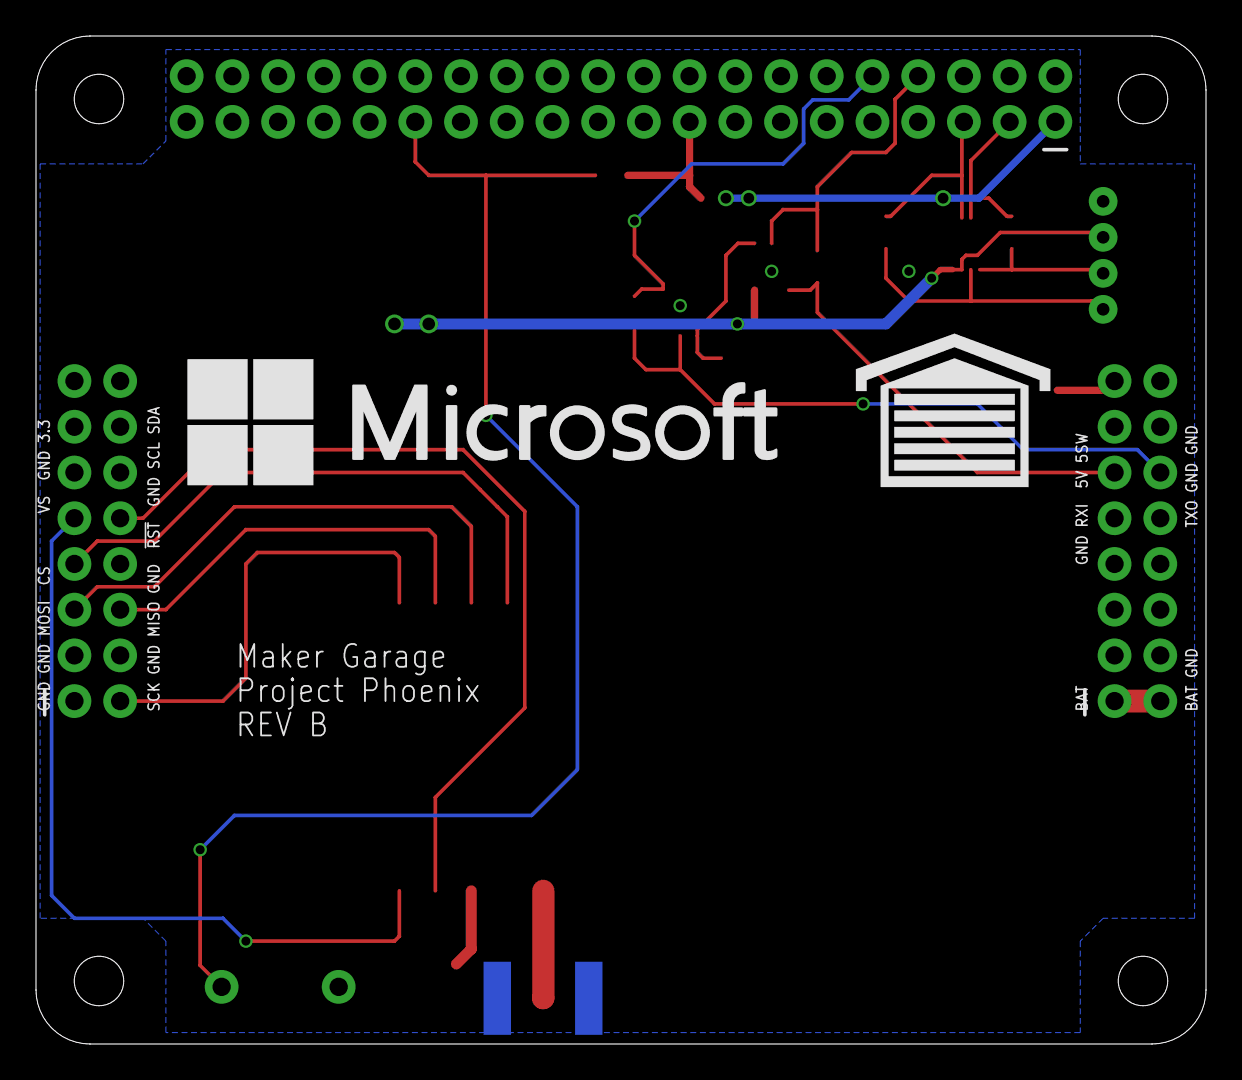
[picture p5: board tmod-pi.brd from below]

Board: 2 copper layers, 65.0 x 56.0 mm, 25 parts (2 on the bottom side), 23 nets.

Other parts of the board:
U$1: MSFT_LOGO
U$2: GARAGE

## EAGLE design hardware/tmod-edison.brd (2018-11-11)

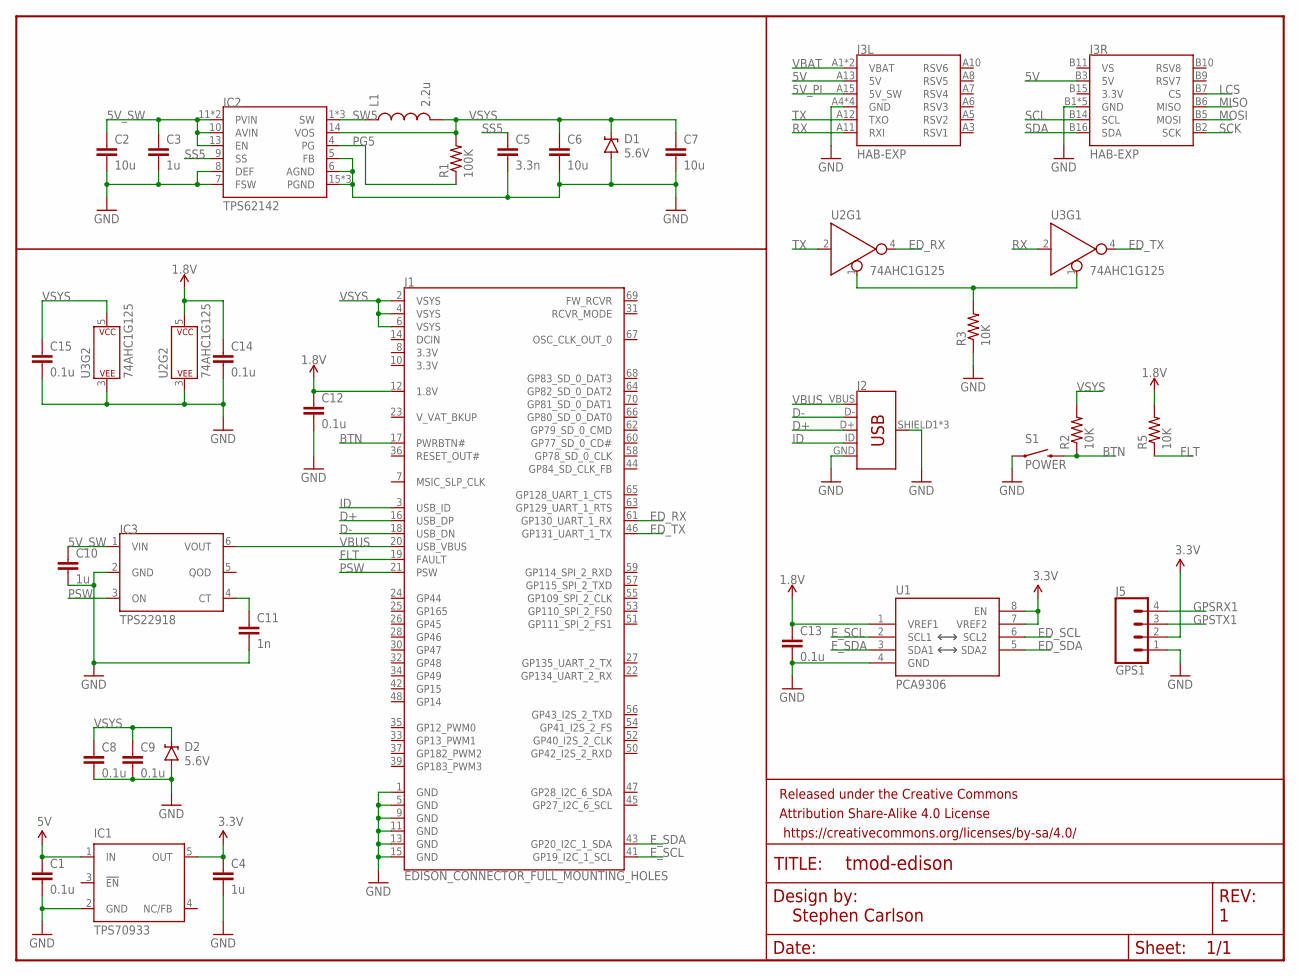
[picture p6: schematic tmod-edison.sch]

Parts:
C1, C8, C9, C12, C13, C14, C15: 0.1u; 0805
C2, C6, C7: 10u; 0805
C3, C4, C10: 1u; 0805
C5: 3.3n; 0805
C11: 1n; 0805
D1, D2: 5.6V; SOD-323
FRAME1: FRAME-LETTERNO_PACKAGE; DUMMY
IC1: TPS70933; SOT23-DBV
IC2: TPS62142; QFN16-3X3MM
IC3: TPS22918; SOT23-6L
J1: EDISON_CONNECTOR_FULL_MOUNTING_HOLES; EDISON_DAUGHTER
J2: USB_MICRO-B_FEMALE-SMT; USB-B-MICRO-SMD
J3: HAB-EXP
J5: GPS1; JST-4-PTH
L1: 2.2u; MPIA4012V2
R1: 100K; 0805
R2, R3, R5: 10K; 0805
S1: POWER; TACTILE-PTH-THIN
U1: PCA9306; PCA9306DC
U2, U3: 74AHC1G125; SOT23-5

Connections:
1.8V: C12.1, C13.1, C14.1, J1.12 (1.8V), R5.2, U1.1 (VREF1), U2.5 (P$V+)
3.3V: C4.1, IC1.5 (OUT), J3.B15 (3.3V), J5.2, U1.7 (VREF2), U1.8 (EN)
5V: C1.1, IC1.1 (IN), J3.A13 (5V), J3.B3 (5V)
5V_PI: J3.A15 (5V_SW)
5V_SW: C2.1, C3.1, C10.1, IC2.10 (AVIN), IC2.11 (PVIN), IC2.12 (PVIN), IC2.13 (EN), IC3.1 (VIN)
BTN: J1.17 (PWRBTN#), R2.1, S1.2
CT: C11.1, IC3.4 (CT)
D+: J1.16 (USB_DP), J2.D+
D-: J1.18 (USB_DN), J2.D-
ED_RX: J1.61 (GP130_UART_1_RX), U2.4 (Y)
ED_SCL: U1.6 (SCL2)
ED_SDA: U1.5 (SDA2)
ED_TX: J1.46 (GP131_UART_1_TX), U3.4 (Y)
E_SCL: J1.41 (GP19_I2C_1_SCL), U1.2 (SCL1)
E_SDA: J1.43 (GP20_I2C_1_SDA), U1.3 (SDA1)
FLT: J1.19 (FAULT), R5.1
GND: C1.2, C2.2, C3.2, C4.2, C5.2, C6.2, C7.2, C8.2, C9.2, C10.2, C11.2, C12.2, C13.2, C14.2, C15.2, D1.A, D2.A, IC1.2 (GND), IC2.5 (FB), IC2.6 (AGND), IC2.7 (FSW), IC2.8 (DEF), IC2.15 (PGND), IC2.16 (PGND), IC2.EXT (PGND), IC3.2 (GND), J1.1 (GND), J1.5 (GND), J1.9 (GND), J1.11 (GND), J1.13 (GND), J1.15 (GND), J2.GND, J2.SHIELD1 (SHIELD), J2.SHIELD2 (SHIELD), J2.SHIELD3 (SHIELD), J3.A4 (GND), J3.A9 (GND), J3.A14 (GND), J3.A16 (GND), J3.B1 (GND), J3.B4 (GND), J3.B8 (GND), J3.B12 (GND), J3.B13 (GND), J5.1, R3.1, S1.1, U1.4 (GND), U2.3 (P$V-), U3.3 (P$V-)
GPSRX1: J5.4
GPSTX1: J5.3
ID: J1.3 (USB_ID), J2.ID
LCS: J3.B7 (CS)
MISO: J3.B6 (MISO)
MOSI: J3.B5 (MOSI)
PG5: IC2.4 (PG), R1.1
PSW: IC3.3 (ON), J1.21 (PSW)
RX: J3.A11 (RXI), U3.2 (A)
SCK: J3.B2 (SCK)
SCL: J3.B14 (SCL)
SDA: J3.B16 (SDA)
SS5: C5.1, IC2.9 (SS)
SW5: IC2.1 (SW), IC2.2 (SW), IC2.3 (SW), L1.1
TX: J3.A12 (TXO), U2.2 (A)
UART_EN: R3.2, U2.1 (!EN), U3.1 (!EN)
VBAT: J3.A1 (VBAT), J3.A2 (VBAT)
VBUS: IC3.6 (VOUT), J1.20 (USB_VBUS), J2.VBUS
VS: J3.B11 (VS)
VSYS: C6.1, C7.1, C8.1, C9.1, C15.1, D1.C, D2.C, IC2.14 (VOS), J1.2 (VSYS), J1.4 (VSYS), J1.6 (VSYS), L1.2, R1.2, R2.2, U3.5 (P$V+)

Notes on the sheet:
Stephen Carlson

Board: 2 copper layers, 36 parts (2 on the bottom side), 25 nets, no tracks yet.

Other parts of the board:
U$1: MSFT_LOGO
U$2: GARAGE

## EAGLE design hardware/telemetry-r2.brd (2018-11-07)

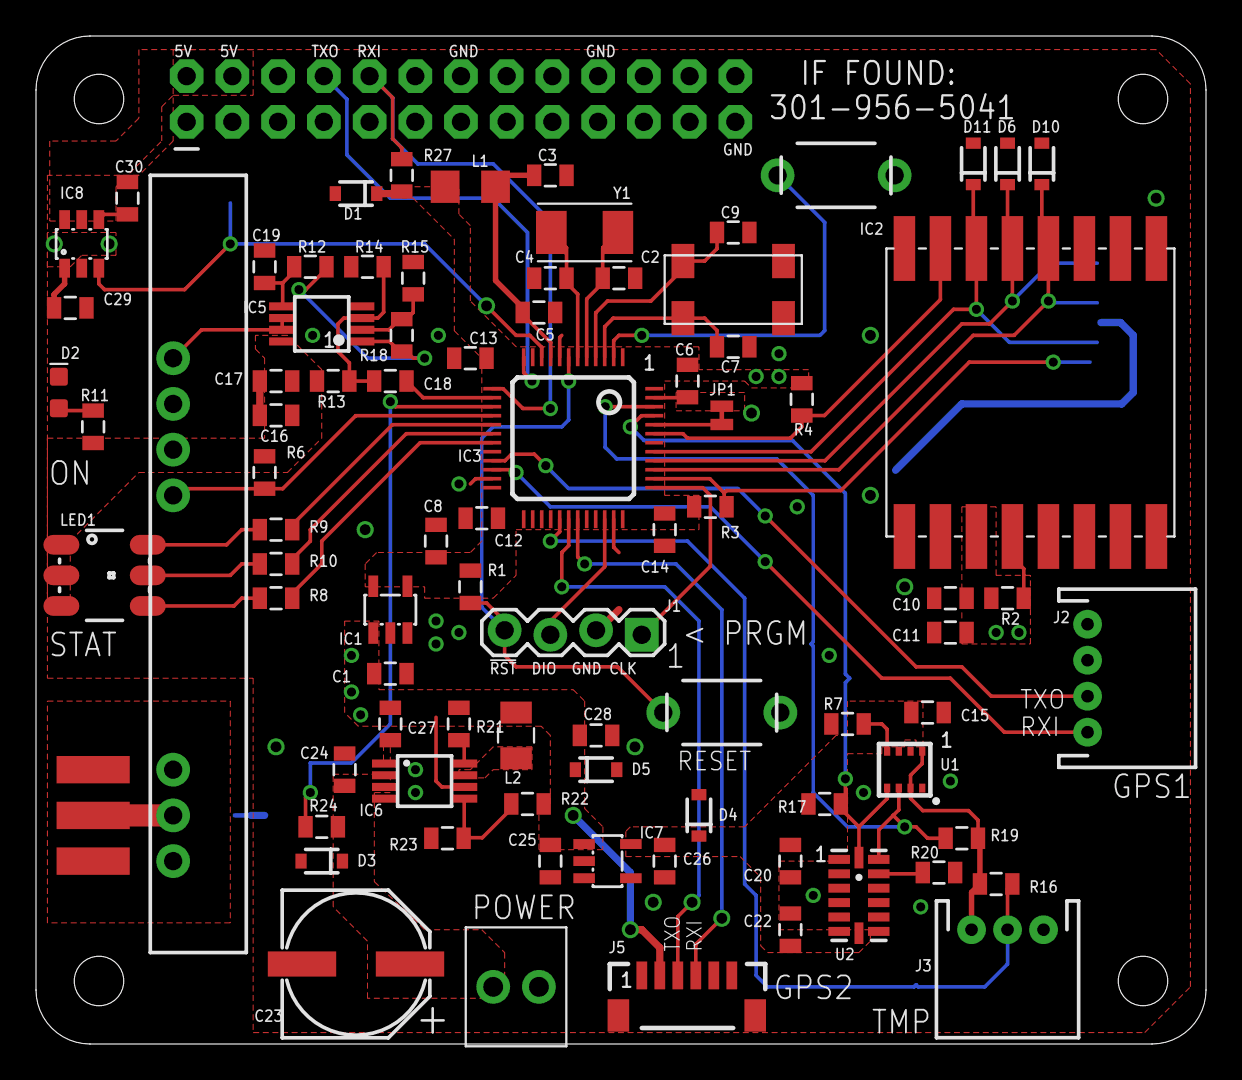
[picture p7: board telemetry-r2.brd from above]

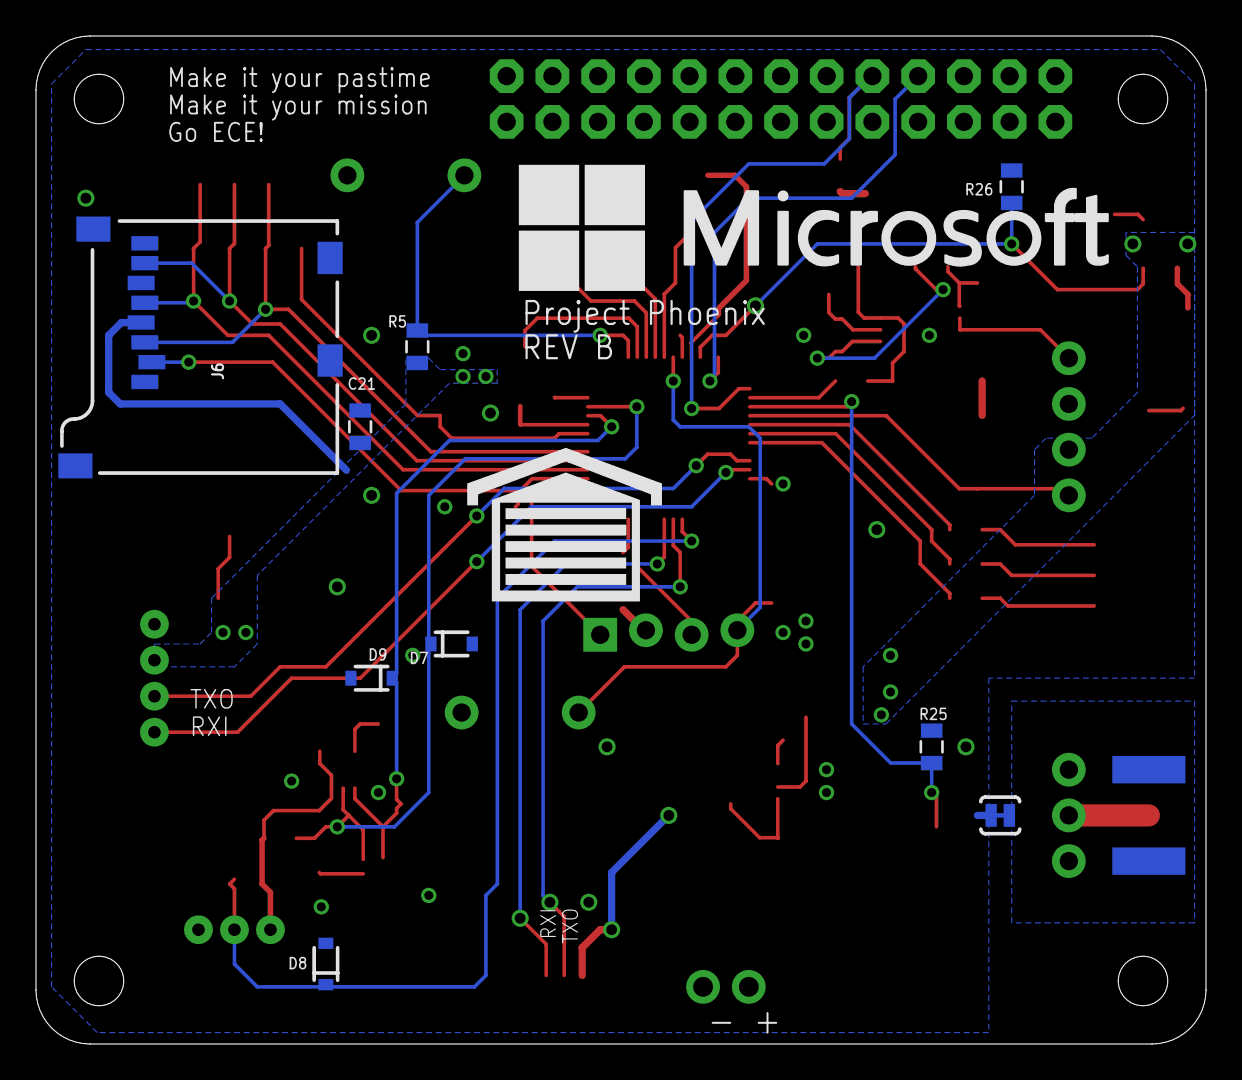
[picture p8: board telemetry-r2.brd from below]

Board: 2 copper layers, 65.0 x 56.0 mm, 99 parts (11 on the bottom side), 55 nets.

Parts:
C1, C5, C6, C10, C12, C13, C14, C15, C17, C22, C25, C29: 0.1u; 0805
C2, C4: 33p; 0805
C3, C8, C16, C21, C24, C26: 1u; 0805
C7, C9: 10p; 0805
C11, C27, C28: 10u; 0805
C18: 330p; 0805
C19: 100p; 0805
C20: 1.0u; 0805
C23: 100u; PANASONIC_E
C30: 1n; 0805
D1, D4, D5, D6, D7, D8, D9, D10, D11: 5.6V; SOD-323
D2: GREEN; LED-0603
D3: 15V; SOD-323
FRAME1, FRAME2: FRAME-LETTERNO_PACKAGE; DUMMY
IC1, IC7: TPS70933; SOT23-DBV
IC2: RA02
IC3: STM32L052C8T6; TQFP48
IC4: HX1
IC5: LMP7702; VSSOP8
IC6: TPS62160; MSOP8
IC8: TPS22918; SOT23-6L
J1: DNP; 1X04_LOCK@1
J2: GPS1; JST-4-PTH
J3: TEMP; JST-3-PTH
J4: POWER; 1X02_SCREW
J5: GPS2; 1X06-1MM
J6: MICRO-SD_CARD_SOCKET; MICRO-SD-SOCKET
J7: RASPBERRYPI-GPIO; 2X13-PI
J$1: SMA_EDGE; SMA-EDGE
JP1: SMT-JUMPER_2_NC_TRACE_NO-SILK
JP2: GND; PAD-JUMPER-2-NC_BY_TRACE_YES_SILK
L1: FERRITE; 1206
L2: 2.2u; 1008
LED1: COM-10866; LED-TRICOLOR-5050
R1, R2, R3, R4, R5, R7, R20, R21, R26, R27: 10K; 0805
R6, R16: 4.7K; 0805
R8, R9: 470; 0805
R10: 560; 0805
R11, R17, R19: 3.3K; 0805
R12: 330K; 0805
R13: 820K; 0805
R14: 220K; 0805
R15, R22, R24: 430K; 0805
R18: 680K; 0805
R23: 82K; 0805
R25: 100K; 0805
S1: RST; TACTILE-PTH-THIN
S2: BTN; TACTILE-PTH-THIN
U1: BME280; BME280_LGA
U2: ADXL345; LGA14
U$1: GARAGE
U$2: MSFT_LOGO
Y1: 8M; CRYSTAL-TXC-7A
Y2: 32768; ABS25

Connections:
3.3V: C6.1, C8.1, C10.1, C11.1, C12.1, C13.1, C14.1, C21.1, D1.C, IC1.5, IC2.3, IC3.1, IC3.24, IC3.36, IC3.48, J2.2, J6.VCC, L1.1, R1.2, R2.2, R3.2, R4.2, R5.2, R27.2
5V: C1.1, C16.1, C17.1, C25.1, C27.1, C28.1, C29.1, D5.C, IC1.1, IC4.5, IC5.8, IC6.6, IC7.1, IC8.1, J5.2, L2.2, LED1.1, LED1.2, LED1.3, R6.2, R11.1, R13.2, R21.2, R22.2
5V_PI: IC8.6, J7.2, J7.4
!LORA_RST!: IC2.4, R2.1
!RST!: IC3.7, J1.4, R1.1, S1.2
A+: C18.2, IC5.3, R13.1, R14.2
A-: IC5.2, R15.2, R18.1
ADXL_SDO: R20.2, U2.12
BC: LED1.4, R8.2
BME_SDO: R7.2, U1.P$5
BOOT0: IC3.44, JP1.1
BTN: IC3.2, R5.1, S2.2
CT: C30.1, IC8.4
DAC: C18.1, IC3.14
FB5: IC6.5, R22.1, R23.2
GC: LED1.6, R9.2
GND: C1.2, C2.2, C3.2, C4.2, C5.2, C6.2, C7.2, C8.2, C9.2, C10.2, C11.2, C12.2, C13.2, C14.2, C15.2, C16.2, C17.2, C19.2, C20.2, C21.2, C22.2, C23.-, C24.2, C25.2, C26.2, C27.2, C28.2, C29.2, C30.2, D1.A, D2.C, D3.A, D4.A, D5.A, D6.A, D7.A, D8.A, D9.A, D10.A, D11.A, IC1.2, IC1.4, IC2.1, IC2.2, IC2.9, IC2.16, IC3.8, IC3.23, IC3.35, IC3.47, IC4.6, IC5.4, IC6.1, IC6.4, IC7.2, IC8.2, J1.2, J2.1, J3.1, J4.2, J5.1, J5.5, J6.GND, J6.GND1, J6.GND3, J7.6, J7.9, J7.14, J7.20, J7.25, JP1.2, JP2.2, R7.1, R14.1, R15.1, R20.1, R23.1, R25.1, R26.2, S1.1, S2.1, U1.P$1, U1.P$7, U2.2, U2.4, U2.5
GPSRX1: IC3.22, J2.4
GPSRX2: IC3.31, J5.4
GPSTX1: IC3.21, J2.3
GPSTX2: IC3.30, J5.3
HXEN: IC3.16, IC4.4, R6.1
K_PI: IC3.10, IC8.3, R26.1
LCS: IC2.15, IC3.43, R4.1
LEDB: IC3.19, R8.1
LEDG: IC3.17, R9.1
LEDR: IC3.18, R10.1
LP1: IC5.1, R12.1, R18.2
LP2: C19.1, IC5.5, R12.2
MISO: D6.C, IC2.13, IC3.40, J6.DO
MOSI: D11.C, IC2.14, IC3.41, J6.DI
OSC32_IN: C7.1, IC3.3, Y2.1
OSC32_OUT: C9.1, IC3.4, Y2.4
OSC_IN: C2.1, IC3.5, Y1.P$1
OSC_OUT: C4.1, IC3.6, Y1.P$2
PG5: IC6.8, R21.1
PLED: D2.A, R11.2
RC: LED1.5, R10.2
RF_HX1: IC4.2, J$1.SIG
RGND: IC4.1, IC4.3, J$1.GND@0, J$1.GND@1, J$1.GND@2, J$1.GND@3, JP2.1
R_RX: IC3.13, J7.10, R27.1
R_TX: IC3.12, J7.8
SCK: D10.C, IC2.12, IC3.39, J6.SCLK
SCL: D9.C, IC3.45, R17.1, U1.P$4, U2.14
SDA: D7.C, IC3.46, R19.1, U1.P$3, U2.13
SDCS: IC3.38, J6.CS, R3.1
SW5: IC6.7, L2.1
SWCLK: IC3.37, J1.1
SWDIO: IC3.34, J1.3
TEMP: D8.C, IC3.29, J3.2, R16.1
TXD: IC4.7, IC5.6, IC5.7
VBAT: C23.+, C24.1, D3.C, IC6.2, IC6.3, J4.1, R24.2
VDDA: C3.1, C5.1, IC3.9, L1.2
VDIV: IC3.15, R24.1, R25.2
VS: C15.1, C20.1, C22.1, C26.1, D4.C, IC7.5, J3.3, R16.2, R17.2, R19.2, U1.P$2, U1.P$6, U1.P$8, U2.1, U2.6, U2.7

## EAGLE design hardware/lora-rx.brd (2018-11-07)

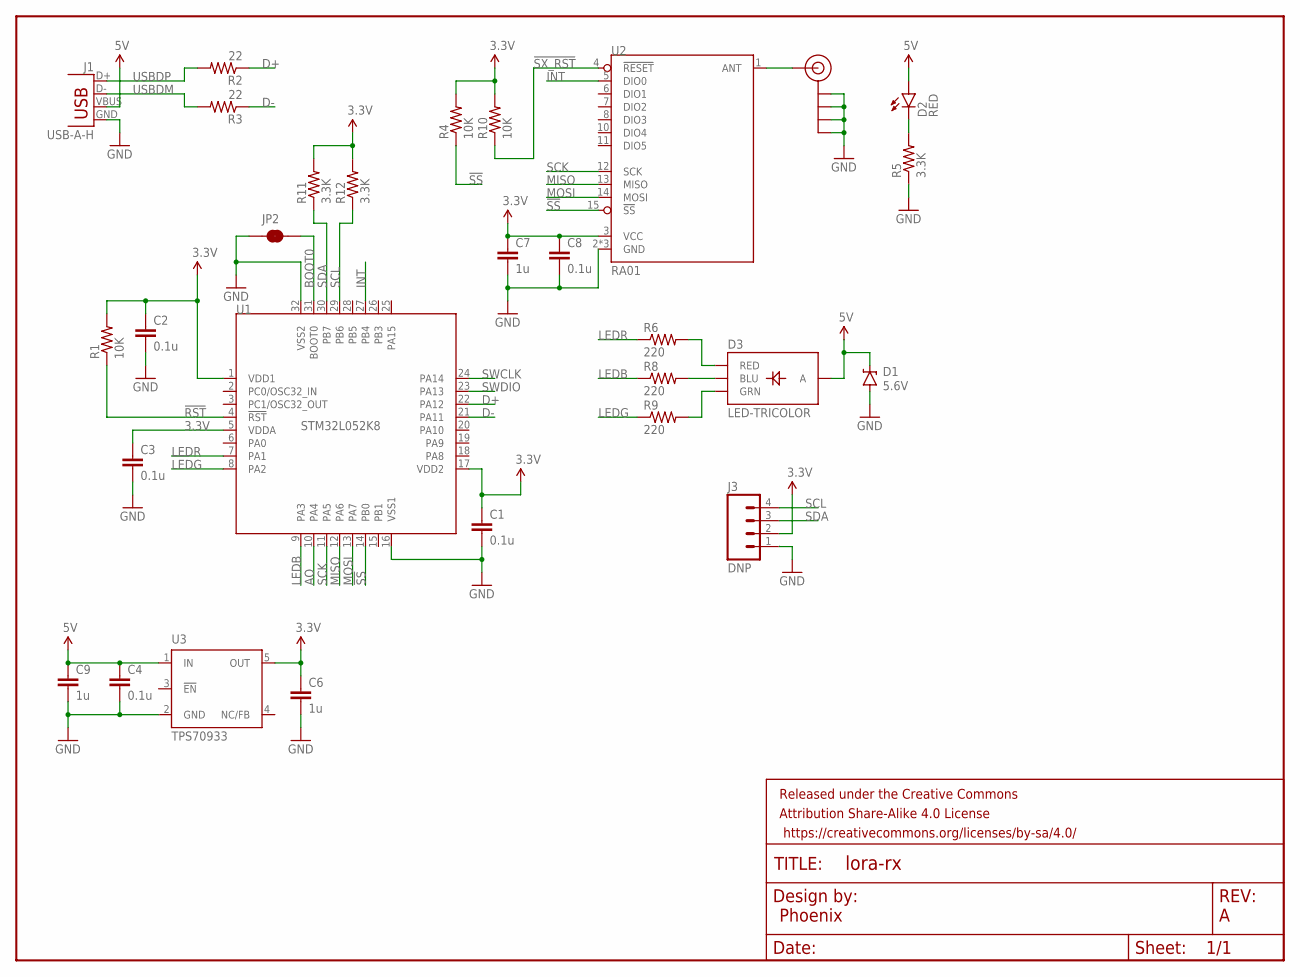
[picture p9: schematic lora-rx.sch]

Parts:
C1, C2, C3, C4, C8: 0.1u; 0805
C6, C7, C9: 1u; 0805
D1: 5.6V; SOD-323
D2: RED; LED-0603
D3: LED-TRICOLOR; LED-TRICOLOR-SMD
FRAME1: FRAME-LETTERNO_PACKAGE; DUMMY
J1: USB-A-H
J2: SMA_EDGE; SMA-EDGE
J3: DNP; 1X04-1.5MM_JST
JP2: JUMPER-SMT_2_NC_TRACE_NO-SILK; SMT-JUMPER_2_NC_TRACE_NO-SILK
R1, R4, R10: 10K; 0805
R2, R3: 22; 0805
R5, R11, R12: 3.3K; 0805
R6, R8, R9: 220; 0805
U1: STM32L052K8; TQFP32-08
U2: RA01
U3: TPS70933; SOT23-DBV

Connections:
3.3V: C1.1, C2.1, C3.1, C6.1, C7.1, C8.1, J3.2, R1.2, R4.2, R10.2, R11.2, R12.2, U1.1 (VDD1), U1.5 (VDDA), U1.17 (VDD2), U2.3 (VCC), U3.5 (OUT)
5V: C4.1, C9.1, D1.C, D2.A, D3.A, J1.VBUS, U3.1 (IN)
!RST!: R1.1, U1.4 (!RST!)
!SS!: R4.1, U1.14 (PB0), U2.15 (!SS!)
!SX_RST!: R10.1, U2.4 (!RESET!)
ANT: J2.SIG (SIGNAL), U2.1 (ANT)
AO: U1.10 (PA4)
BL: D3.B (BLU), R8.2
BOOT0: JP2.2, U1.31 (BOOT0)
D+: R2.1, U1.22 (PA12)
D-: R3.1, U1.21 (PA11)
GL: D3.G (GRN), R9.2
GND: C1.2, C2.2, C3.2, C4.2, C6.2, C7.2, C8.2, C9.2, D1.A, J1.GND, J2.GND@0 (GND), J2.GND@1 (GND), J2.GND@2 (GND), J2.GND@3 (GND), J3.1, JP2.1, R5.1, U1.16 (VSS1), U1.32 (VSS2), U2.2 (GND), U2.9 (GND), U2.16 (GND), U3.2 (GND)
INT: U1.27 (PB4), U2.5 (DIO0)
LEDB: R8.1, U1.9 (PA3)
LEDG: R9.1, U1.8 (PA2)
LEDR: R6.1, U1.7 (PA1)
MISO: U1.12 (PA6), U2.13 (MISO)
MOSI: U1.13 (PA7), U2.14 (MOSI)
PLED: D2.C, R5.2
RL: D3.R (RED), R6.2
SCK: U1.11 (PA5), U2.12 (SCK)
SCL: J3.4, R12.1, U1.29 (PB6)
SDA: J3.3, R11.1, U1.30 (PB7)
SWCLK: U1.24 (PA14)
SWDIO: U1.23 (PA13)
USBDM: J1.D-, R3.2
USBDP: J1.D+, R2.2

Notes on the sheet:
Phoenix

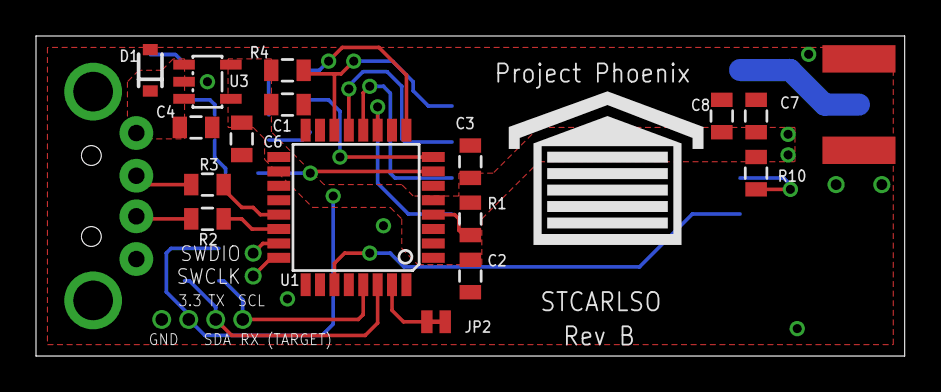
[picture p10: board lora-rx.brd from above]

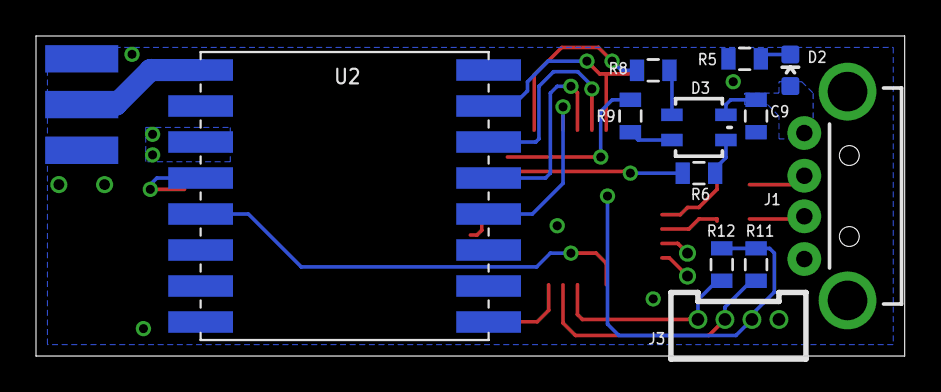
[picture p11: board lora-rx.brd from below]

Board: 2 copper layers, 48.3 x 17.8 mm, 31 parts (13 on the bottom side), 25 nets.

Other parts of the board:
U$1: GARAGE

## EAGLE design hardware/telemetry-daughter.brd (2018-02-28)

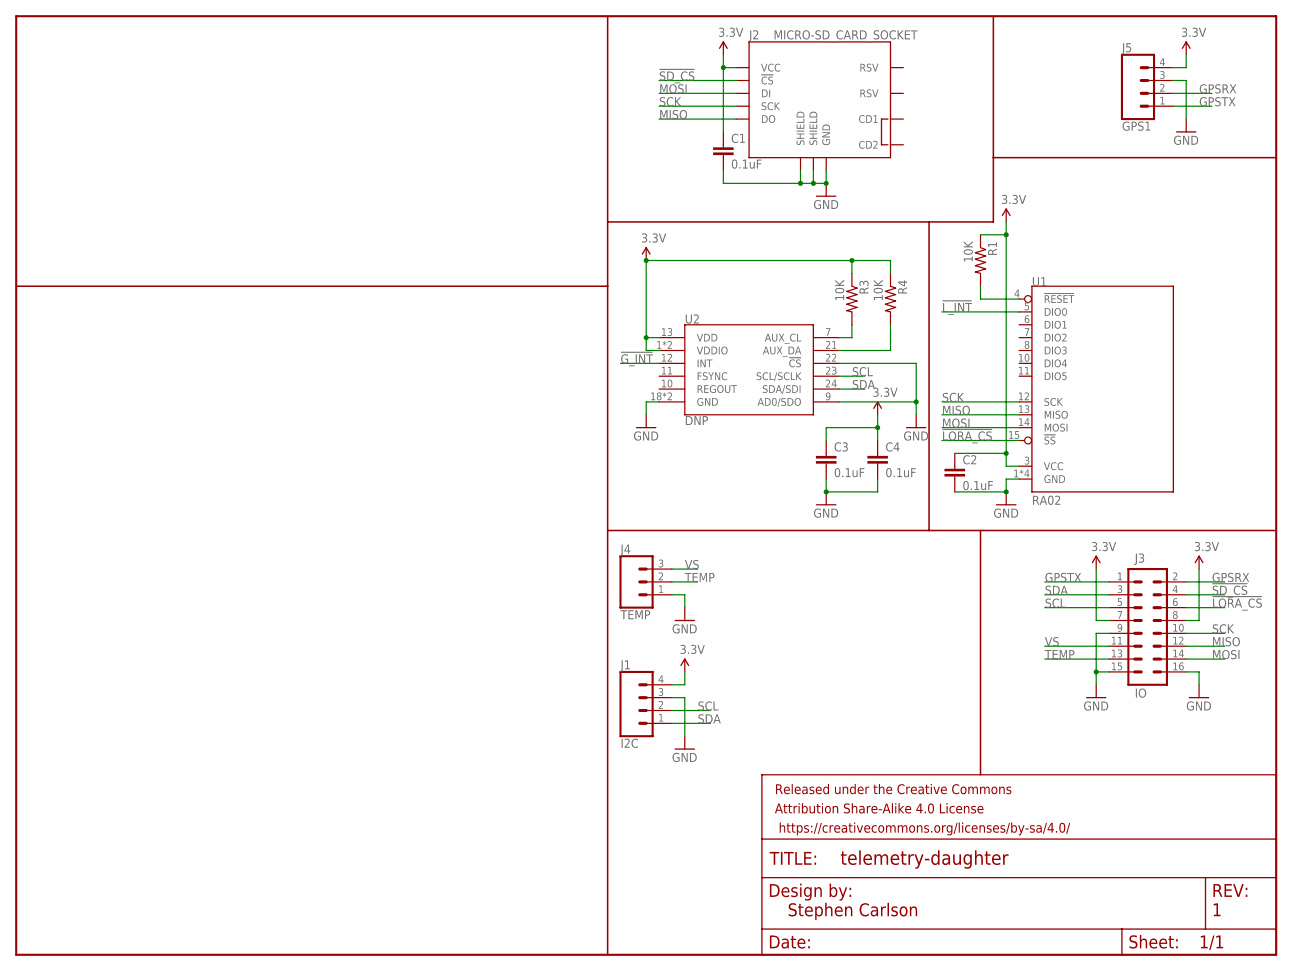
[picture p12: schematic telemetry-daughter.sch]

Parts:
C1, C2, C3, C4: 0.1uF; 0603
FRAME1: FRAME-LETTERNO_PACKAGE; DUMMY
J1: I2C; JST-4-PTH
J2: MICRO-SD_CARD_SOCKET; MICRO-SD-SOCKET
J3: IO; 2X8
J4: TEMP; JST-3-PTH
J5: GPS1; JST-4-PTH
R1, R3, R4: 10K; 0805
U1: RA02
U2: DNP; QFN24-3X3

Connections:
3.3V: C1.1, C2.1, C3.1, C4.1, J1.4, J2.VCC, J3.7, J3.8, J5.4, R1.1, R3.1, R4.1, U1.3 (VCC), U2.1 (VDDIO), U2.8 (VDDIO), U2.13 (VDD)
!G_INT!: U2.12 (INT)
!LORA_CS!: J3.6, U1.15 (!SS!)
!LORA_RST!: R1.2, U1.4 (!RESET!)
!L_INT!: U1.5 (DIO0)
!SD_CS!: J2.CS (!CS), J3.4
AUX_CL: R3.2, U2.7 (AUX_CL)
AUX_DA: R4.2, U2.21 (AUX_DA)
GND: C1.2, C2.2, C3.2, C4.2, J1.3, J2.GND, J2.GND1 (SHIELD), J2.GND3 (SHIELD), J3.9, J3.15, J3.16, J4.1, J5.3, U1.1 (GND), U1.2 (GND), U1.9 (GND), U1.16 (GND), U2.9 (AD0/SDO), U2.18 (GND), U2.20 (GND), U2.22 (!CS)
GPSRX: J3.2, J5.2
GPSTX: J3.1, J5.1
MISO: J2.DO, J3.12, U1.13 (MISO)
MOSI: J2.DI, J3.14, U1.14 (MOSI)
SCK: J2.SCLK (SCK), J3.10, U1.12 (SCK)
SCL: J1.2, J3.5, U2.23 (SCL/SCLK)
SDA: J1.1, J3.3, U2.24 (SDA/SDI)
TEMP: J3.13, J4.2
VS: J3.11, J4.3

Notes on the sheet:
Stephen Carlson



Board: 2 copper layers, 47.2 x 56.0 mm, 17 parts (2 on the bottom side), 16 nets.

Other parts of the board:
U$1: GARAGE
U$2: MSFT_LOGO

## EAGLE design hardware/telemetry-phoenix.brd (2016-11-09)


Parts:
C1, C2, C3, C4, C10, C11, C14, C16, C23, C26, C28, C29, C34: 0.1u; 0805
C5, C12, C13, C18, C22, C36: 1u; 0805
C6, C7: 33p; 0805
C8, C9: 10p; 0805
C19, C20: 10u; 0805
C21: 100u; PANASONIC_E
C24: 1.0u; 0805
C25: 330p; 0805
C39: 100p; 0805
D1, D13, D15: 15V; SOD-323
D2, D4, D5, D6, D7, D8, D9, D10, D11, D12: 5.6V; SOD-323
D3: COM-10866; LED-TRICOLOR-5050
FRAME1, FRAME2: FRAME-LETTERNO_PACKAGE; DUMMY
IC2, IC10: TPS70933; SOT23-DBV
IC3: BME280; BME280_LGA
IC4: STM32L052C8T6; TQFP48
IC5: TPS62160; MSOP8
IC6: HX1
IC7: LMP7702; SO08
IC8: ADXL345; LGA14
IC9, IC11: VN5160S-E; SO8
J1: GPS1; 1X04
J2: RASPBERRYPI-GPIO; 2X13-PI
J3: POWER; 1X10_SCREW
J4: GPS2; 1X06-1MM
J5: DNP; 1X04_LOCK
J6: SMA_EDGE; SMA-EDGE
J9: IO; 2X8
JP2: GND; PAD-JUMPER-2-NC_BY_TRACE_YES_SILK
JP3: SDA; PAD-JUMPER-2-NC_BY_TRACE_YES_SILK
JP4: SCL; PAD-JUMPER-2-NC_BY_TRACE_YES_SILK
L1: 2.2u; 1008
L2: FERRITE; 1206
Q1: SI4202DY; SO8
R1, R3, R6, R7, R9, R12, R26, R43, R44, R45, R48, R49, R50, R51: 10K; 0805
R4, R21, R22, R25, R28, R29, R30: 100; 0805
R5, R8, R32: DNP; 0805
R10, R19, R56: 430K; 0805
R11: 82K; 0805
R13, R14: 220; 0805
R15: 330; 0805
R16: 820K; 0805
R17: 220K; 0805
R18: 680K; 0805
R20, R46, R47: 100K; 0805
R23: 4.7K; 0805
R27: 330K; 0805
S1: RST; TACTILE-PTH-THIN
S2: BTN; TACTILE-PTH-THIN
Y1: 32768; ABS25
Y2: 8M; CRYSTAL-TXC-7A

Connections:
3.3V: C1.1, C2.1, C3.1, C10.1, C11.1, C12.1, C13.1, D12.C, IC2.5 (OUT), IC4.1 (VLCD), IC4.24 (VDD), IC4.36 (VDD_USB), IC4.48 (VDD), J1.4, J9.7, J9.8, L2.1, R1.2, R5.2, R6.2, R7.2, R8.2, R26.2, R32.2, R43.2, R48.2, R49.2
3V_PI: J2.1 (3.3V)
3V_PI2: J2.17 (3.3V)
5V: C14.1, C19.1, C20.1, C22.1, C26.1, C28.1, C34.1, D2.C, D3.1 (GRN-A), D3.2 (RED-A), D3.3 (BLU-A), IC2.1 (IN), IC5.6 (VOS), IC6.5 (VCC), IC7.8 (V+), IC9.5 (VCC), IC9.8 (VCC), IC10.1 (IN), J4.2, L1.2, R9.2, R10.2, R16.2, R23.2
5V_PI: IC9.6 (OUTPUT), IC9.7 (OUTPUT), J2.2 (5V), J2.4 (5V)
15V_OUT: IC11.6 (OUTPUT), IC11.7 (OUTPUT), J3.4
!RST!: IC4.7 (!RST!), J5.4, R1.1, S1.2
+9V: J3.6, J3.7, J3.8
A+: C25.2, IC7.3 (+IN), R16.1, R17.2
A-: IC7.2 (-IN), R18.1, R56.2
ACB: Q1.4 (G), R45.2
ADXL_SDO: IC8.12 (SDO), R12.2
ALT_CTRL: D13.C, J3.9, Q1.5 (D), Q1.6 (D)
BC: D3.4 (BLU-C), R13.2
BME_SDO: IC3.P$5 (SDO/ADR), R3.2
BOOT0: IC4.44 (BOOT0), R26.1
BTN: IC4.2 (PC13), R7.1, S2.2
B_LORA: D10.C, J9.6, R22.2
B_MISO: D4.C, J9.12, R28.1
B_MOSI: D9.C, J9.14, R25.1
B_SCK: D8.C, J9.10, R4.1
CRB: Q1.2 (G), R44.2
CS: IC4.38 (PA15), R6.1, R22.1
CUT_ROPE: D15.C, J3.10, Q1.7 (D), Q1.8 (D)
DAC: C25.1, IC4.14 (PA4)
D_PI: IC9.4 (STAT_DIS), R51.2
D_RAD: IC11.4 (STAT_DIS), R50.2
FB5: IC5.5 (FB), R10.1, R11.2
GC: D3.6 (GRN-C), R14.2
GND: C1.2, C2.2, C3.2, C4.2, C5.2, C6.2, C7.2, C8.2, C9.2, C10.2, C11.2, C12.2, C13.2, C14.2, C16.2, C18.2, C19.2, C20.2, C21.-, C22.2, C23.2, C24.2, C26.2, C28.2, C29.2, C34.2, C36.2, C39.2, D1.A, D2.A, D4.A, D5.A, D6.A, D7.A, D8.A, D9.A, D10.A, D11.A, D12.A, D13.A, D15.A, IC2.2 (GND), IC3.P$1 (GND1), IC3.P$7 (GND2), IC4.8 (VSSA), IC4.23 (VSS), IC4.35 (VSS), IC4.47 (VSS), IC5.1 (GND), IC5.4 (GND), IC6.6 (GND), IC7.4 (V-), IC8.2 (GND), IC8.4 (GND), IC8.5 (GND), IC9.1 (GND), IC10.2 (GND), IC11.1 (GND), J1.3, J2.6 (GND), J2.9 (GND), J2.14 (GND), J2.20 (GND), J2.25 (GND), J3.2, J3.3, J3.5, J4.1, J4.5, J5.2, J9.9, J9.15, J9.16, JP2.2, Q1.1 (S), Q1.3 (S), R3.1, R11.1, R12.1, R17.1, R20.1, R46.1, R47.1, R50.1, R51.1, R56.1, S1.1, S2.1
GPSRX: IC4.22 (PB11), J1.2
GPSRX2: IC4.31 (PA10), J4.4
GPSTX: IC4.21 (PB10), J1.1
GPSTX2: IC4.30 (PA9), J4.3
HXEN: IC4.16 (PA6), IC6.4 (EN), R23.1
INT: IC8.8 (INT1)
INT2: IC8.9 (INT2)
K_PI: IC4.10 (PA0), IC9.2 (INPUT), R48.1
K_RAD: IC4.29 (PA8), IC11.2 (INPUT), R49.1
L1: J9.2, R21.1
L2: J9.1, R29.1
L3: J9.4, R30.1
LED1: IC4.13 (PA3), R21.2
LED2: IC4.12 (PA2), R29.2
LED3: IC4.11 (PA1), R30.2
LEDB: IC4.19 (PB1), R13.1
LEDG: IC4.17 (PA7), R14.1
LEDR: IC4.18 (PB0), R15.1
LP1: IC7.1 (OUT), R18.2, R27.1
LP2: C39.1, IC7.5 (+IN), R27.2
LS1: J2.22 (GP25), R44.1, R46.2
LS2: J2.18 (GP24), R45.1, R47.2
MISO: IC4.40 (PB4), R28.2
MOSI: IC4.41 (PB5), R25.2
OSC32_IN: C8.1, IC4.3 (OSC32_IN), Y1.1
OSC32_OUT: C9.1, IC4.4 (OSC32_OUT), Y1.4 (2)
OSC_IN: C7.1, IC4.5 (OSC_IN), Y2.P$1 (1)
OSC_OUT: C6.1, IC4.6 (OSC_OUT), Y2.P$2 (2)
PG5: IC5.8 (PG), R9.1
RC: D3.5 (RED-C), R15.2
RF_HX1: IC6.2 (RFOUT), J6.SIG (SIGNAL)
RGND: IC6.1 (RFGND), IC6.3 (RFGND), J6.GND@0 (GND), J6.GND@1 (GND), J6.GND@2 (GND), J6.GND@3 (GND), JP2.1
R_CS0: J2.24 (CE0)
R_CS1: J2.26 (CE1)
R_MISO: J2.21 (MISO)
R_MOSI: J2.19 (MOSI)
R_RX: IC4.42 (PB6), J2.10 (RXI), R43.1
R_SCK: J2.23 (SCLK)
R_SCL: J2.5 (SCL), JP4.1
R_SDA: J2.3 (SDA), JP3.1
R_TX: IC4.43 (PB7), J2.8 (TXO)
SCK: IC4.39 (PB3), R4.2
SCL: D7.C, IC3.P$4 (SCK/SCL), IC4.45 (PB8), IC8.14 (SCL), J9.5, JP4.2, R5.1
SDA: D5.C, IC3.P$3 (SDI/SDA), IC4.46 (PB9), IC8.13 (SDA), J9.3, JP3.2, R8.1
SW5: IC5.7 (OUT), L1.1
SWCLK: IC4.37 (PA14), J5.1
SWDIO: IC4.34 (PA13), J5.3
TEMP: D6.C, IC4.28 (PB15), J9.13, R32.1
TXD: IC6.7 (TXD), IC7.6 (-IN), IC7.7 (OUT)
VBAT: C18.1, C21.+, C29.1, D1.C, IC5.2 (VIN), IC5.3 (EN), IC11.5 (VCC), IC11.8 (VCC), J3.1, R19.2
VDDA: C4.1, C5.1, IC4.9 (VDDA), L2.2
VDIV: IC4.15 (PA5), R19.1, R20.2
VS: C16.1, C23.1, C24.1, C36.1, D11.C, IC3.P$2 (!CS), IC3.P$6 (VDDIO), IC3.P$8 (VDD), IC8.1 (VDD), IC8.6 (VS), IC8.7 (CS), IC10.5 (OUT), J9.11

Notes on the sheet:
Stephen Carlson
Single Point Ground



Board: 2 copper layers, 65.0 x 56.0 mm, 113 parts (3 on the bottom side), 74 nets.

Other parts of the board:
U$1: GARAGE
U$2: MSFT_LOGO

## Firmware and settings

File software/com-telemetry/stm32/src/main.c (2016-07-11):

#include <hx1/hx1.h>

#include <aprs/aprs.h>

#include <test/test.h>
#include <test/trace_uart.h>

#include <gps/nmea_buffer.h>

#include <signals/signals.h>

#include <st_link/st_link.h>

#include <telemetry/telemetry.h>

#include <copernicus/copernicus.h>

#include <system_clock/system_clock.h>

#include <stm32l0xx_hal.h>

Telemetry g_telemetry = { 0 };
NmeaMessage g_nmeaMessage = { 0 };

int main(void)
{
#ifdef TEST
    HAL_Init();
    configSystemClock();
    stLinkInit();
    traceUartInit();

    EXECUTE_TESTS();

    traceUartDeInit();

    for (;;)
    {
    }
#else
    HAL_Init();
    configSystemClock();
    initializeSignals();
    stLinkInit();
    copernicusUartInit();

    signalInitialized(true);

    bool hasGpsMessage = false;

    for (;;)
    {
        // TODO distinguish between modes:
        // - ascending close to the ground
        // - ascending close to balloon popping event
        // - descending close to the ground
        // - landed not moving
        // - landed moving (water landing or on the truck :) )

        if (nmeaReadMessage(&g_nmeaRingBuffer, &g_nmeaMessage))
        {
            hasGpsMessage = true;
        }

        if (!isAprsMessageTransmitting())
        {
            // TODO add delay between APRS messages
            // TODO send APRS telemetry message
            if (hasGpsMessage)
            {
                if (encodeNmeaAprsMessage(&CALLSIGN_SOURCE, &g_nmeaMessage, &g_ax25EncodedAprsMessage))
                {
                    transmitAprsMessage();
                }
            }
        }
    }
#endif
}

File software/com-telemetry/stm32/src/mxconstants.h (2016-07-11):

#pragma once

#define COPERNICUS_GPIO               GPIOB
#define COPERNICUS_UART               LPUART1
#define COPERNICUS_UART_TX_Pin        GPIO_PIN_10
#define COPERNICUS_UART_RX_Pin        GPIO_PIN_11
#define COPERNICUS_UART_IRQn          LPUART1_IRQn
#define COPERNICUS_GPIO_AF4_UART      GPIO_AF4_LPUART1
#define COPERNICUS_LPUART_IRQHandler  LPUART1_IRQHandler
#define COPERNICUS_GPIO_CLK_ENABLE    __HAL_RCC_GPIOB_CLK_ENABLE
#define COPERNICUS_UART_CLK_ENABLE    __HAL_RCC_LPUART1_CLK_ENABLE
#define COPERNICUS_UART_CLK_DISABLE   __HAL_RCC_LPUART1_CLK_DISABLE
#define COPERNICUS_UART_FORCE_RESET   __HAL_RCC_LPUART1_FORCE_RESET
#define COPERNICUS_UART_RELEASE_RESET __HAL_RCC_LPUART1_RELEASE_RESET

#define TRACE_UART                      USART2
#define TRACE_UART_IRQHandler           USART2_IRQHandler
#define TRACE_DMA_IRQHandler            DMA1_Channel4_5_6_7_IRQHandler
#define TRACE_DMA_CLK_ENABLE()          __HAL_RCC_DMA1_CLK_ENABLE()
#define TRACE_UART_CLK_ENABLE()         __HAL_RCC_USART2_CLK_ENABLE()
#define TRACE_UART_TX_GPIO_CLK_ENABLE() __HAL_RCC_GPIOA_CLK_ENABLE()
#define TRACE_UART_TX_PIN               GPIO_PIN_2
#define TRACE_UART_TX_AF                GPIO_AF4_USART2
#define TRACE_UART_TX_GPIO_PORT         GPIOA
#define TRACE_UART_TX_DMA_CHANNEL       DMA1_Channel4
#define TRACE_UART_TX_DMA_REQUEST       DMA_REQUEST_4
#define TRACE_UART_DMA_TX_IRQn          DMA1_Channel4_5_6_7_IRQn
#define TRACE_UART_IRQn                 USART2_IRQn
#define TRACE_UART_FORCE_RESET()        __HAL_RCC_USART2_FORCE_RESET()
#define TRACE_UART_RELEASE_RESET()      __HAL_RCC_USART2_RELEASE_RESET()

#define HX1_DAC                 DAC1
#define HX1_DAC_CHANNEL         DAC_CHANNEL_1
#define HX1_DAC_TRIGGER         DAC_TRIGGER_T6_TRGO
#define HX1_DAC_ALIGN           DAC_ALIGN_12B_R
#define HX1_DAC_CLK_ENABLE      __HAL_RCC_DAC_CLK_ENABLE
#define HX1_DAC_FORCE_RESET     __HAL_RCC_DAC_FORCE_RESET
#define HX1_DAC_RELEASE_RESET   __HAL_RCC_DAC_RELEASE_RESET
#define HX1_TIMER               TIM6
#define HX1_TIMER_CLK_ENABLE    __HAL_RCC_TIM6_CLK_ENABLE
#define HX1_TIMER_FORCE_RESET   __HAL_RCC_TIM6_FORCE_RESET
#define HX1_TIMER_RELEASE_RESET __HAL_RCC_TIM6_RELEASE_RESET
#define HX1_DMA_INSTANCE        DMA1_Channel2
#define HX1_DMA_IRQn            DMA1_Channel2_3_IRQn
#define HX1_DMA_IRQHandler      DMA1_Channel2_3_IRQHandler
#define HX1_DMA_CLK_ENABLE      __HAL_RCC_DMA1_CLK_ENABLE
#define HX1_GPIO_CLK_ENABLE()     __HAL_RCC_GPIOA_CLK_ENABLE()
#define HX1_GPIO_PIN            GPIO_PIN_4
#define HX1_GPIO_PORT           GPIOA

#define HX1_ENABLE_Pin       GPIO_PIN_5
#define HX1_ENABLE_GPIO_Port GPIOA

#define SIGNAL_TIMER                     TIM3
#define SIGNAL_TIMER_CLK_ENABLE          __HAL_RCC_TIM3_CLK_ENABLE
#define SIGNAL_TIMER_CHANNEL_GPIO_PORT() __HAL_RCC_GPIOA_CLK_ENABLE();__HAL_RCC_GPIOB_CLK_ENABLE()
#define SIGNAL_TIMER_CHANNEL_RED         TIM_CHANNEL_2
#define SIGNAL_GPIO_AF_CHANNEL_RED       GPIO_AF2_TIM3
#define SIGNAL_GPIO_PIN_RED              GPIO_PIN_7
#define SIGNAL_GPIO_CHANNEL_RED          GPIOA
#define SIGNAL_TIMER_CHANNEL_GREEN       TIM_CHANNEL_3
#define SIGNAL_GPIO_AF_CHANNEL_GREEN     GPIO_AF2_TIM3
#define SIGNAL_GPIO_PIN_GREEN            GPIO_PIN_0
#define SIGNAL_GPIO_CHANNEL_GREEN        GPIOB
#define SIGNAL_TIMER_CHANNEL_BLUE        TIM_CHANNEL_4
#define SIGNAL_GPIO_AF_CHANNEL_BLUE      GPIO_AF2_TIM3
#define SIGNAL_GPIO_PIN_BLUE             GPIO_PIN_1
#define SIGNAL_GPIO_CHANNEL_BLUE         GPIOB

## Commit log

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2016-04-06 aligning stm32 generated code to comply with CubeMX so I can regenerate it as much as I need
2016-04-09 Add basic schematic for telemetry board, has only the microcontroller basics pending the sensor/power discussion outcome
    [telemetry-r1.sch]
2016-04-10 added a bit of code to bring USART up. still having issues getting the data
    [main.c, mxconstants.h]
2016-04-10 added main thread uart comms, need to migrate code to interrupt handler (probably)
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2016-04-17 Update schematic. Still no layout, but the majority of components are on the sheet, including temp/humidity sensors, HX1, regulators, and SD card.
    Many connectors are still missing. No LoRA footprint has yet been added.
    [telemetry-r1.sch]
2016-04-24 Add more connectors and parts to schematic. Please review it and let me know what is still missing. In particular, no LoRA module is on board.
    [telemetry-r1.sch]
2016-04-27 lpuart is now workin in interrupt mode and feeds characters to nmea buffer func
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2016-05-03 Start layout for telemetry board. Initially had it almost 80% done, but started over to get a better route on those last few nets
    [telemetry-r1.brd, telemetry-r1.sch]
2016-05-04 Fully route telemtery PCB, please review
    [telemetry-r1.brd, telemetry-r1.sch]
2016-05-14 added DAC configuration (need to play with timer settings), migrated part of the APRS code
2016-05-20 added open ocd configs to git repository
    [st_nucleo_l0.cfg]
2016-05-21 added AFSK DAC/DMA code but it's too slow without FPU so I will need to improve it by a factor of 7 or so
    [main.c]
2016-06-01 fixed some bugs, improved perf a little bit, but debug is still too slow for 16MHz (need to think if it's possible to speed up without sacrificing accuracy)
    [main.c]
2016-06-03 Fix a few issues on the telemetry PCB. Add schematic (no layout) for bottom/sensors board.
    [bottom-r1.sch, telemetry-r1.brd, telemetry-r1.sch]
2016-06-20 Route bottom sensors PCB, please review
    [bottom-r1.brd, bottom-r1.sch]
2016-06-22 added SO08 breakout board to test OP-Amp
    [SO08-breakout.brd, SO08-breakout.sch]
2016-06-22 made board a bit smaller
    [SO08-breakout.brd]
2016-06-25 Update telemetry board to include Pavel's new LPF
    [telemetry-r1.brd, telemetry-r1.sch]
2016-06-25 Fix broken photocell routing
    [telemetry-r1.brd, telemetry-r1.sch]
2016-06-26 Add schematic for "beta" balloon, no layout, but needs a theory of operation check on the solar charging system
    [telemetry-b1.sch]
2016-06-27 renamed ADC ports to use GoPro4/2 is running photo sensors
    [telemetry-r1.brd, telemetry-r1.sch]
2016-06-27 Fixed swapped pins in DAC filter
    [telemetry-b1.sch, telemetry-r1.brd, telemetry-r1.sch]
2016-06-27 - made breakout board for SO08 a bit smaller - split APRS code to APRS/AX.25/AFSK files
    [SO08-breakout.brd]
2016-07-01 added test trace over USART2 (ST-Link) so tests are easier to debug
2016-07-02 - added limited float to string for testing purposes (no large exponent support, so number should fit in int) - fixed test trace output not being sent fully
    [main.c]
2016-07-02 - migrated to use silicon CRC calculation (slight improvement in perf) - moved STM32 tests specific code to src folder - renamed FCS to CRC
2016-07-02 - improved fcs code a bit - added disble crc timer code
2016-07-04 - disabled usage of A05 as error output (on NUCLEO it's mapped to LED2) - added HX1 enable / disable code
    [main.c, mxconstants.h]
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2016-07-07 Several small fixes to PCB. No pin swap to DAC2 was performed.
    [telemetry-r1.brd]
2016-07-07 Commit a partial, horribly broken PCB for the beta board.
    This branch should be copied to master and removed when the changes are done.
    [telemetry-b1.brd]
2016-07-07 Update HX1 filter to match latest experimental results
    [telemetry-r1.brd, telemetry-r1.sch]
2016-07-09 - cleaned up code a bit - added more detailed error handling - refactored some code into modules
    [copernicus.c]
2016-07-10 Copy filter changes from main Telemetry PCB. Needs a relay rework.
    [telemetry-b1.brd, telemetry-b1.sch]
2016-07-11 - a bit more error handling changes - fixed FCS to CRC everywhere - placed HX1 code into one module - placed st-link to module - placed system clock to module - HX1 DMA will be initialized every time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
    [copernicus.c, crc.c, hx1.c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]
2016-07-13 Strip unnecessary relay, and fix most RF stubs
    [telemetry-b1.brd, telemetry-b1.sch]
2016-07-19 Work on beta PCB layout. Most placement is done, probably will have no room for the HIH (or put it on the back).
    [telemetry-b1.brd, telemetry-b1.sch]
2016-07-22 Work on layout on beta PCB. Need to swap i2c and swd headers
    [telemetry-b1.brd, telemetry-b1.sch]
2016-07-22 Finish routing all traces on beta board. Needs a silkscreen pass.
    [telemetry-b1.brd, telemetry-b1.sch]
2016-07-22 Silkscreen gloss on beta board
    [telemetry-b1.brd, telemetry-b1.sch]
2016-07-23 fixed eclipse debug config settings to use L073 chip instead of generic L0 config
    [st_nucleo_l073.cfg]
2016-07-24 fixed but introduced during refactoring of DMA usage (enable disable on every use as it's going to be shared between HX1 and SPI)
    [hx1.c]
2016-08-02 Swap HXEN pin to 5VT pin
    [telemetry-b1.brd, telemetry-b1.sch, telemetry-r1.brd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]
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2016-10-04 Fix I2C pull-up resistors in beta/regular boards; add Phoenix board and some datasheets
    [telemetry-b1.brd, telemetry-b1.sch, telemetry-phoenix.brd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]
2016-10-13 Add Phoenix telemetry PCB
    [telemetry-phoenix.brd, telemetry-phoenix.sch]
2016-10-13 Add GPS1 connector to Phoenix board
    [telemetry-phoenix.brd, telemetry-phoenix.sch]
2016-10-14 Rotate and reroute Phoenix board, much cleaner!
    [telemetry-phoenix.brd, telemetry-phoenix.sch]
2016-10-14 Adjust layout near regulator on Phoenix board
    [telemetry-phoenix.brd]
2016-10-14 Satisfy Adi on Phoenix power supply routing
    [telemetry-phoenix.brd, telemetry-phoenix.sch]
2016-10-18 A few minor tweaks to Phoenix board
    [telemetry-phoenix.brd, telemetry-phoenix.sch]
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2016-11-09 Add CRC init, untested
    [telemetry-phoenix.brd]
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2016-11-30 Massive clock system overhaul in new telemetry code, now supports configuration at 16 or 32 MHz.
    Automatically falls back to the HSI if the (new) HSE does not start, and to the LSI if the LSE fails to start.
    [main.c]
2016-12-06 Add LoRA receiver dongle board
    [lora-rx.brd, lora-rx.sch]
2017-01-26 Fixed serial lines and LEDs, but having issues with 32/64-bit math functions from libgcc blowing up the code size to 128MB.
    [main.c]
2017-02-01 Fix several I2C bugs in STM32 code. BME280 sensor is now operational.
    [main.c]
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2017-03-23 Fix several bugs in analog signal generation and increase frequency to 128 Ksps. Still fast enough, looks beautiful, but does not decode.
    [main.c]
2018-01-18 Start daughtercard for Phoenix telemetry board to break out cables
    [telemetry-daughter.brd, telemetry-daughter.sch]
2018-01-18 Update telemetry daughter board, a few nets left to route, need to check connector placement and sizing
    [telemetry-daughter.brd, telemetry-daughter.sch]
2018-01-19 Connect CS and AD0 pins on the MPU9250. Fix a few small routing issues near the connector.
    [telemetry-daughter.brd, telemetry-daughter.sch]
2018-01-26 Route final two nets for daughtercard
    [telemetry-daughter.brd]
2018-02-08 Change daughter card to use right angle SMA connector to remove conflict with enclosure
    [telemetry-daughter.brd, telemetry-daughter.sch]
2018-02-28 Change LoRA footprint on daughter card to the RA-02 which is easier to obtain
    [telemetry-daughter.brd, telemetry-daughter.sch]
2018-11-02 Start work on revised telemetry MCU using lessons learned from second HAB launch
    [SO08-breakout.brd, SO08-breakout.sch, bottom-r1.brd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]
2018-11-07 Initial route for HAB v3 modular base board
    [lora-rx.brd, lora-rx.sch, telemetry-r2.brd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]
2018-11-07 Add silkscreen to HAB base board
    [tmod-base.brd, tmod-base.sch]
2018-11-11 Started work on Pi and Edison example application cards, neither is complete
    [tmod-base.brd, tmod-base.sch, tmod-edison.brd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]
2018-11-16 Continued work on the Pi-style application board
    [tmod-base.brd, tmod-pi.brd]
2019-01-25 Add BOM for modular telemetry base
    [tmod-base.csv]
2019-04-06 Route out RSV5 and RSV6 to microcontroller pins
    [tmod-base.brd, tmod-base.csv, tmod-base.sch]
2019-04-06 Finalize routing on the Raspberry PI-compatible Application Module. 5V net is not routed, but is not used on the module so not required.
    [tmod-pi.brd, tmod-pi.sch]
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2019-07-15 Rotate LED by 180 degrees to match the actual part
    [tmod-base.brd, tmod-base.csv, tmod-base.sch]
2019-07-24 Start work on new automated base station. Add BOM for Pi application board. Fix mirrored INA219 footprint and LED on base board
    [fadic.sch, tmod-base.brd, tmod-pi.csv]

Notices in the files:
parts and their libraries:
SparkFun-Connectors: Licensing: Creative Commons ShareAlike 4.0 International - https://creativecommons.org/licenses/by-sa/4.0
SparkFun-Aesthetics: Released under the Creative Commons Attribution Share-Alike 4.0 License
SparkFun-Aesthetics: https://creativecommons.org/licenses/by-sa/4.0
